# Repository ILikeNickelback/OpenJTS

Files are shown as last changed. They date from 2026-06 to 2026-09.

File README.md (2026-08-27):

# OpenJTS

Open-source JTS (Joliot-type Spectrophotometer).
Designed for measuring light-induced signals in photosynthesis research using fluorescence and spectroscopy protocols.
Two acquisition modes are supported: sequence mode and frequency mode.
---

## Overview

This OpenJTS project includes the necessary software to control the JTS, the PCB design and BOMs, the stp files and the docs.
Certain manuals might be found on other adresses for easier reading.

## Requirements

### Hardware
- MCC DAQ board (compatible with [mcculw](https://github.com/mccdaq/mcculw))
- ESP32 microcontroller connected via USB serial

### Software
- Windows 10/11 (64-bit)
- [pixi](https://prefix.dev/) — used for environment and dependency management

---

## Installation

**1. Install pixi** (if not already installed):

```powershell
iwr -useb https://pixi.sh/install.ps1 | iex
```

**2. Clone the repository:**

```powershell
git clone https://github.com/ILikeNickelback/OpenJTS.git
cd OpenJTS
```

**3. Install the environment:**

```powershell
pixi install
```

This resolves all dependencies from `pixi.toml` using the conda-forge channel, including Python 3.14, NumPy, DearPyGUI, mcculw, loguru, and pyserial.

---

## Running

```powershell
pixi run python software/src/main.py
```

The application opens maximised at 1920×1200. Per-monitor DPI scaling is applied automatically.

---

## Project structure

```
OpenJTS/
├── software/
│   └── src/
│       ├── main.py                   # Entry point
│       ├── config/
│       │   ├── config.json           # ADC, ESP32, LED, and app settings
│       │   ├── sequences.json        # Saved sequence / frequency library
│       │   └── fonts.py              # DPG font setup
│       ├── core/
│       │   ├── app_state.py          # Shared application state
│       │   ├── event_bus.py          # Pub/sub event bus
│       │   ├── layout.py             # Window creation and tab registry
│       │   ├── layout_manager.py     # Panel position/size configuration
│       │   ├── window_base.py        # Base class for all panel windows
│       │   └── workspace_manager.py  # Save / load workspace JSON
│       ├── hardware/
│       │   ├── adc_base.py           # MCC DAQ base driver (buffer, reader thread)
│       │   ├── adc_sequence.py       # Sequence-mode ADC subclass
│       │   ├── adc_frequency.py      # Frequency-mode ADC subclass
│       │   ├── adc_calibration.py    # Calibration ADC subclass
│       │   └── esp32.py              # ESP32 serial driver
│       ├── workers/
│       │   ├── base_worker.py        # Threaded acquisition base class
│       │   ├── sequence_worker.py    # Worker for sequence acquisitions
│       │   ├── frequency_worker.py   # Worker for frequency acquisitions
│       │   └── calibration_worker.py # Worker for 1 Hz LED calibration
│       ├── sequence_builders/        # Sequence language parser and preview builder
│       ├── windows/
│       │   ├── main_window.py        # Top-level DPG window and menu bar
│       │   ├── home_window.py        # Home tab (device status, experiment list)
│       │   ├── experiment/           # Per-experiment tab and sub-tab builders
│       │   ├── panels/               # Control panels (settings, library, metadata…)
│       │   └── plots/                # Lineplot and sequence preview plot
│       └── utils/
├── pixi.toml                         # Dependency manifest
└── pyproject.toml                    # Ruff lint config
```

---

## Configuration

All settings live in `software/src/config/config.json`:

```json
{
  "General":  { "app_name": "JTS", "fontsize": 15 },
  "ADC":      { "board_num": 0, "channel_count": 8, "sampling_rate": 200000 },
  "LED":      { "actinic_light_max": 100, "detection_light_max": 100 },
  "ESP32":    { "baud_rate": 115200, "timeout": 1 },
  "Sampling": { "samples_per_trigger": 8, ... }
}
```

The sequence and frequency preset library is stored in `software/src/config/sequences.json` and is editable directly from the **Sequence library** panel inside the application.

---

## Sequence language

Sequences are written in a compact domain-specific language. A few examples:

| Token | Meaning |
|---|---|
| `D` | Detection pulse |
| `A[100]` | Set actinic light to 100 % |
| `300µs` | 300µs delay|
| `4(100msD)` | Repeat `100msD` four times |
| `L` | Laser |
| `T` | Set time start point |

Example — ECS measurement:
```
4(100msD) A[100] 50ms A[0] 300µsD 1msD 2msD 5(5msD) 5(10msD) 5(20msD) 5(50msD) 5(100msD)
```

---

## Key features

- **Multiple experiments** — open several experiment tabs simultaneously, each with its own isolated event bus, settings, and results.
- **Averaging and ignore runs** — configurable per sequence: discard N warm-up runs then average M acquisitions.
- **Baseline subtraction** — subtract the mean of the first N points from every result.
- **Live plot** — real-time streaming of incoming ADC data during acquisition.
- **Sample container** — name, toggle, and export individual result series to JSON.
- **Sequence history** — timestamped log of every completed acquisition.
- **Workspace save / restore** — full experiment state (sequences, parameters, results, metadata) saved to JSON and reloadable.
- **Autosave** — a snapshot is written to `software/src/temp/autosave.json` after every completed acquisition.

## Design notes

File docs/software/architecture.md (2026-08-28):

# Architecture

## What It Is

OpenJTS is a desktop application (Python 3.14) for running experiments on the OpenJTS hardware. The user defines a sequence of light pulses and sees the results plotted in real time. It drives a specific DAQ board and can interact with an ESP32 over serial. The UI is built on the **DearPyGui (DPG)** library.

---

## Architecture

Launching `main.py` creates a DPG context and viewport, initializes the ADC and ESP32 instances, and starts the render loop, which updates the UI each frame in response to events.

The app is event-driven, built on two pillars:

- **AppState** — a single shared object holding all runtime data (experiments, sequences, parameters, hardware references). It is passed into every window at construction.
- **EventBus** — a publish/subscribe message broker. Windows never call each other directly; they publish named events with keyword arguments, and subscribers are invoked synchronously.

---

## Threading

OpenJTS makes heavy use of threads and queues, driven by one DPG constraint: item creation, deletion, and configuration must happen on the main DPG thread. Threads communicate by writing to queues that other threads can safely read.

There are four thread roles:

- **Main thread** — owns all DPG item creation, deletion, and configuration, the per-frame callback, and event dispatch.
- **Worker thread** — waits on a command queue and manages the acquisition: starts/stops it, launches the ADC reader thread, and turns raw data blocks into scalar points pushed to the result queue.
- **ADC reader thread** — polls the ADC every 1 ms, accumulating samples into a trigger block; when the block is full (one detection pulse) it pushes to the data queue.
- **Polling thread** — reads the result queue and applies statistical processing (averaging, baseline, etc.), then hands results to the main thread for plotting.

In short: the reader collects raw samples, the worker turns them into scalar data points, the polling thread does statistical processing and routing, and the main thread owns all rendering.

---

## Window Hierarchy

- **Main window** — top-level DPG primary window; hosts the menu bar (File, Tools) and the `TabbedWindowManager`.
- **Home window** — static tab showing device connection status and a table of all experiments with their metadata.
- **Experiment tab** — one experiment's content, with its own isolated `tab_bus` and a nested sub-tab bar.

---

## Acquisition Pipeline

The flow from user input to plotted results:

**Define → Load → Start → Acquire → Return → Display**

1. **Define** — the user types sequence strings (e.g. `4(100msD)A[100]20msA[0]300µsD`); multiple sequences are allowed.
2. **Load** — the decoder expands repeats and converts units into a token list stored in `AppState`, then publishes `sequence_list_ready`.
3. **Start** — resets the sequence index, records the start time, and dispatches `configure` + `start` commands to the worker.
4. **Acquire** — the worker reads blocks from the ADC, computes ΔI/I per block, and streams live points back through the result queue.
5. **Return** — the polling thread applies baseline subtraction and averaging, then routes finished results to the main thread through a thread-safe queue.
6. **Display** — the main thread drains that queue each frame and publishes to the UI, updating the plot and sample container.

> For the internals of any stage — decoding rules, the total-time formula, baseline/averaging logic, event names and payloads — see the inline comments and autodocs.

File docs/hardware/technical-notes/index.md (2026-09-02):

# Technical notes

This section details the technical choices for the different modules when it is needed.

```{toctree}
:maxdepth: 2
:caption: Technical notes

LED-control
optical-transmission
measurement-strategy
preamp-design
VCCS-design
waveform-generation
```

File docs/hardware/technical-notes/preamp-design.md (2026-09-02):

# Transimpedance Amplifier Design

The transimpedance amplifier (TIA) is a critical building block of the JTS optical detection system. It is responsible for converting the photocurrent emitted by the photodiode into a stable, low-noise voltage readable by the Data Acquisition (DAQ) system.

A useful baseline reference on stable TIA design principles is available via [DigiKey's TIA Design Guide](https://www.digikey.fr/fr/articles/how-to-design-stable-transimpedance-amplifiers-automotive-medical-systems).

---

## 1. System Specifications & Constraints

Designing the TIA requires balancing **gain, bandwidth, and linearity**. A primary challenge is managing the wide dynamic range of optical signals: varying optical filters or samples significantly changes light transmission. The TIA gain must resolve small signals without saturating under peak light levels (though light intensity from the excitation LED can be modulated).

### Photodiode Characteristics
Based on the photodiode specifications, the sensor is a Hamamatsu Si PIN photodiode reverse-biased at **48 V**, yielding:
- **Terminal Capacitance ($C_d$):** $\approx 47\text{ pF}$
- **Dark Current:** Negligible (a few nA)

### Bandwidth Target
To resolve a **20 µs** light pulse without excessive edge rounding, the amplifier's rise time ($t_r$) should be roughly $\frac{1}{17}$ of the pulse width:

$$t_r \approx \frac{20\text{ }\mu\text{s}}{17} \approx 1.2\text{ }\mu\text{s}$$

$$f_{-3\text{dB}} = \frac{0.35}{t_r} \approx 300\text{ kHz}$$

We establish **300 kHz** as the minimum closed-loop bandwidth target for every gain range.

### Feedback Resistance Choice
The highest expected photocurrent is around **50 µA**. The ADC can accept up to **+10 V**, so the maximum allowable feedback resistance is:

$$R_f = \frac{U}{I} = \frac{10\text{ V}}{50\text{ }\mu\text{A}} = 200\text{ k}\Omega$$

To maintain high dynamic range without complex dynamic range switching, the feedback resistance is fixed at **$R_f = 200\text{ k}\Omega$**.

### Stability Equations
The photodiode's terminal capacitance ($C_d$) creates a pole with the feedback resistor ($R_f$) that erodes phase margin and causes gain peaking/ringing if left uncompensated. A feedback capacitor ($C_f$) in parallel with $R_f$ restores phase margin.

The standard TIA design equations are:

$$f_{-3\text{dB}} \approx \sqrt{\frac{\text{GBW}}{2\pi \cdot R_f \cdot C_d}}$$

$$C_f \approx \frac{1}{2\pi \cdot R_f \cdot f_{-3\text{dB}}} \approx \sqrt{\frac{C_d}{2\pi \cdot R_f \cdot \text{GBW}}}$$

---

## 2. Architectural Options

### Option A: Single-Stage High-Voltage TIA

A single transimpedance stage converts photocurrent directly into a $\pm 10\text{ V}$ signal driving the ADC.

```
                  +---| Rf (200 kΩ) |---+
                  |                     |
                  +---| Cf (~1.3 pF)|---+
                  |                     |
[ Photodiode ] -> (- Inverting )        |
                  (            ) [ Op-Amp ] ----> [ Low-Pass Filter ] -> [ ADC (±10V) ]
     ( Ground ) -> (+ Non-Invert)
```

#### Key Requirements:
- **Gain-Bandwidth Product (GBW):** Minimum **$5.3\text{ MHz}$** to hit 300 kHz bandwidth with $R_f = 200\text{ k}\Omega$ and $C_d = 47\text{ pF}$.
- **Input Bias Current ($I_b$):** Must be ultra-low (FET/CMOS input, $\le 10\text{ pA}$) to prevent significant DC offset errors across $200\text{ k}\Omega$.
- **Power Supply Rails:** Must support $\pm 15\text{ V}$ or $\pm 12\text{ V}$ to deliver full $\pm 10\text{ V}$ output to the ADC.

#### Suitable Op-Amp Candidates:
- **ADA4622-1:** JFET input, $\text{GBW} = 8\text{ MHz}$, $I_b = 10\text{ pA}$, $\pm 15\text{ V}$ supplies.
- **ADA4637-1:** High-speed JFET, $\text{GBW} = 79\text{ MHz}$, $I_b = 1\text{ pA}$, $\pm 15\text{ V}$ supplies.

---

### Option B: Two-Stage Architecture (OPA657 + AD797)

A hybrid approach decoupling the ultra-low noise, high-speed current conversion stage from the high-voltage voltage gain stage.

```
=== STAGE 1: TIA Stage (±5V Supply) ===       === STAGE 2: Voltage Gain Stage (±15V Supply) ===

                  +--| Rf1 (50 kΩ) |--+                                 +--| Rf2 (3 kΩ) |--+
                  |                   |                                 |                  |
                  +--| Cf1 (4.3 pF) |-+                                 +--| Rg2 (1 kΩ) |--+
                  |                   |                                                    |
[ Photodiode ] -> (- Inv )            |                                  (- Inv )          |
                  ( OPA657 ) ---------+-----> [ AC/DC Coupling ] ------> ( AD797 ) --------+--> [ ADC (±10V) ]
     ( Ground ) -> (+ Non-Inv )                                          (+ Non-Inv )
                                                                              |
                                                                          ( Ground )
```

#### Stage 1: Current-to-Voltage (OPA657)
- **Role:** High-speed TIA operating on low-voltage rails ($\pm 5\text{ V}$).
- **Performance:** JFET inputs ($I_b \approx 2\text{ pA}$), ultra-high bandwidth ($\text{GBW} = 1.6\text{ GHz}$), ultra-low voltage noise ($4.8\text{ nV}/\sqrt{\text{Hz}}$).
- **Stability Note:** The OPA657 is a *decompensated* op-amp stable only for high-frequency noise gain $\ge 7$. With $C_d = 47\text{ pF}$ and $C_f \approx 4.3\text{ pF}$, the high-frequency noise gain is:
  $$\text{Noise Gain}_{\infty} = 1 + \frac{C_d}{C_f} = 1 + \frac{47\text{ pF}}{4.3\text{ pF}} \approx 11.9$$
  Since $11.9 > 7$, Stage 1 is inherently stable.

#### Stage 2: Voltage Gain & Level Shifting (AD797)
- **Role:** Voltage amplifier running on $\pm 15\text{ V}$ rails to scale the Stage 1 output to match the ADC's $\pm 10\text{ V}$ range.
- **Performance:** Driven by the low-impedance output of Stage 1, erasing input bias current limitations ($250\text{ nA}$) while delivering ultra-low noise ($0.9\text{ nV}/\sqrt{\text{Hz}}$).

#### Power Supply Infrastructure:
- Requires dedicated **linear voltage regulators (LDOs)** (e.g., ADP7118 / ADP7182 or 78L05 / 79L05) to generate clean $\pm 5\text{ V}$ rails from the main $\pm 15\text{ V}$ supplies. *Resistor voltage dividers cannot be used for powering the OPA657 due to dynamic current draw variations.*

---

## 3. Comparison Matrix

| Feature / Metric | Option A: Single-Stage (e.g. ADA4622) | Option B: Two-Stage (OPA657 + AD797) |
|---|---|---|
| **Circuit Complexity** | Low (Single IC, simple layout) | Medium-High (2 ICs, LDO regulators) |
| **Supply Rails** | Single dual-rail pair ($\pm 15\text{ V}$) | Dual rail pairs ($\pm 5\text{ V}$ LDOs & $\pm 15\text{ V}$) |
| **Noise Performance** | Good (limited by single-stage trade-offs) | Superior (ultra-low noise OPA657 front-end) |
| **Bandwidth Headroom** | Moderate (8–79 MHz GBW) | Exceptional (1.6 GHz GBW front-end) |
| **PCB Footprint** | Small | Moderate |

---

## 4. Downstream Filtering & Protection

- **Anti-Aliasing Filter:** A single-pole RC low-pass filter ($f_c \approx 500\text{ kHz} - 1\text{ MHz}$) follows the TIA before the ADC to restrict out-of-band noise without distorting 300 kHz signals.
- **ADC Protection:** The DAQ system's ADC input natively tolerates overvoltage up to **$\pm 25\text{ V}$**. Because the maximum output from an AD797 or single $\pm 15\text{ V}$ stage is $\approx \pm 13.5\text{ V}$, **no protective clamping diodes are required**, preventing parasitic diode capacitance from degrading high-frequency signal integrity.

---

## 5. Critical PCB Layout Guidelines

1. **Summing Node Isolation:** Keep $R_f$, $C_f$, and photodiode trace lengths as short as physically possible, routing directly to the op-amp inverting pin.
2. **Ground Plane Clearance:** Cut away (void) the internal ground and power plane copper directly underneath the inverting input pin, photodiode anode pad, and feedback traces to eliminate parasitic capacitance loading the input.
3. **Guard Ringing:** Surround the inverting node with a grounded guard trace driven near the same potential to prevent surface leakage currents across high-resistance feedback paths.
4. **Supply Separation:** Keep the **48 V** photodiode reverse-bias line isolated and well-filtered from sensitive analog signal traces to prevent power supply ripple from coupling into the summing node.

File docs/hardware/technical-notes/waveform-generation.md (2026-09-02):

# Waveform Generation

OpenJTS produces its actinic and detection light through **two independent paths**:

- The **DAQ board** (an MCC card, driven by [`hardware/adc_base.py`](../../../software/src/hardware/adc_base.py) and its subclasses) generates the full, timing-critical stimulus waveform for real acquisitions — actinic light, detection flashes, and the trigger that tells the acquisition side when to sample — all locked to a single 500 kHz clock.
- The **ESP32** (documented in [Firmware](../../firmware/firmware.md)) is a simpler, general-purpose controller. In the current software it is mostly used for one-shot commands (set a constant actinic level, stop), but its firmware also implements a full standalone sequencer with its own DAC and digital trigger outputs, including a laser trigger the DAQ path does not have.

This note explains how each side actually turns numbers into light, given the channel and resolution constraints each hardware has to work with.

---

## 1. DAQ Board: One 16-bit Waveform, Three Channels, 500 kHz

### 1.1 The channel budget

The board's output scan is started with a single call:

```python
ul.daq_out_scan(
    self.board_num,
    [0, 1, 1],
    [ChannelType.ANALOG, ChannelType.ANALOG, ChannelType.DIGITAL],
    [ao_range, ao_range, ULRange.NOTUSED],
    3,
    self.rate,                       # 500 000 Hz
    self._total_waveform_samples * 3,
    self._memhandle,
    options=(ScanOptions.BACKGROUND | ScanOptions.CONTINUOUS),
)
```

— [`ADCBase.start_acquisition()`](../../../software/src/hardware/adc_base.py)

Three channels, no more: **AO0** (actinic), **AO1** (detection), and one **digital port** (trigger). There is nothing left over for a laser-trigger channel, which is why the DAQ path currently cannot drive a laser — `sequence_waveform_builder.py` parses the `L` (laser) token from a sequence string but its handler is a no-op:

```python
elif item["type"] == "laser":
    pass
```

— [`SequenceWaveformBuilder._parse_sequence` / `build()`](../../../software/src/sequence_builders/sequence_waveform_builder.py)

The ESP32 firmware *does* have two dedicated laser-trigger pins (§2.3) — that logic has simply not been ported to the DAQ-driven waveform yet, because doing so would need a fourth output channel this board doesn't have to spare.

### 1.2 One buffer, interleaved

The board has no concept of "three separate waveforms." It streams a single flat `uint16` array, and consumes it three samples at a time — one value per channel, in channel order, per output tick:

```
index:   0    1    2    3    4    5    6    7    8   ...
         ch0  ch1  ch2  ch0  ch1  ch2  ch0  ch1  ch2  ...
         └── tick 0 ──┘└── tick 1 ──┘└── tick 2 ──┘
```

Both waveform builders ([`SequenceWaveformBuilder`](../../../software/src/sequence_builders/sequence_waveform_builder.py) for the sequence mini-language, [`FrequencyWaveformBuilder`](../../../software/src/sequence_builders/frequency_waveform_builder.py) for sine-modulated acquisitions) build this interleaved array in Python with NumPy strided views (`interleaved[0::3]`, `[1::3]`, `[2::3]`) so each channel can be filled independently before being copied into the DMA buffer:

```python
interleaved = np.empty(total_samples * 3, dtype=np.uint16)
ch0_raw = interleaved[0::3]   # actinic
ch1_raw = interleaved[1::3]   # detection flash
ch2_raw = interleaved[2::3]   # trigger marker
```

Because all three channels are drawn from the *same* buffer at the *same* clock, they are sample-accurate relative to each other — the trigger marker, the detection flash, and the actinic level at any instant are guaranteed to be aligned to within one 2 µs tick (1 / 500 kHz). That's what makes it possible to hit the 2–3 µs sampling window described in [Measurement Strategy](measurement-strategy.md) without any drift between the light and the acquisition trigger.

### 1.3 16-bit resolution, ±10 V range

The board's AO range is bipolar ±10 V, addressed with the full 16-bit count space (`counts_max = 65535`). A percentage intensity (0–100 %) is mapped to a count with:

```python
counts = counts_max * (0.5 + 0.5 * intensity_percent / 100) - offset
```

so 0 % sits near mid-scale count (0 V) and 100 % sits near full-scale count (+10 V) — the same 0.5 + 0.5·x mapping is used for both the actinic channel (ch0) and the detection flash amplitude (ch1). The `offset` term (`actinic_light_offset` / `detection_light_offset` in `config.json`) compensates for the LED driver / VCCS non-linearity described in [VCCS Design](VCCS-design.md).

### 1.4 Channel 0 — actinic light

Ch0 carries whatever actinic waveform the experiment calls for:

- **Sequence mode** — a step function: each `N!` token in the sequence string sets a constant count from that point forward, until the next `N!` token overwrites it (`ch0_raw[current_sample:] = intensity_counts`).
- **Frequency mode** — a genuine sine wave, sampled at the full 500 kHz rate: `sine = amplitude * np.sin(2*np.pi*freq*t + phase) + offset`, converted to counts sample-by-sample. Because the analog output is a real DAC stream and not a switched PWM signal, arbitrary waveforms (sine, or anything else) come for free — this is the same reasoning behind choosing analog output + VCCS over PWM in [LED Control](LED-control.md).

### 1.5 Channel 1 — detection flash

Ch1 stays at 0 except for 20 µs analog pulses (`pulse_width_samples = int(rate * 20e-6)` → 10 samples at 500 kHz), placed either at each `D` token (sequence mode) or on an evenly-spaced grid of `normal_pulses_per_period` flashes per sine period (frequency mode). Because this is a genuine analog channel, the flash amplitude is fully adjustable (`detection_led_intensity`, 0–100 %) — unlike the ESP32's detection output (§2.2), which is only ever fully on or fully off.

### 1.6 Channel 2 — the trigger

Ch2 is digital: each sample is either `0` or `0xFFFF` (all bits of the port driven at once). It is used purely to mark acquisition timing for the AI (input) scan, which is started with `ScanOptions.EXTTRIGGER | RETRIGMODE` — every rising edge on this channel re-arms the input scan and captures `samples_per_trigger` points. Two kinds of markers are written per flash:

- `number_of_points_before_flash` short (10 µs) pre-pulses, 50 µs apart, ending flush with the start of the analog flash — these sample the baseline used for the DC-subtraction described in [Measurement Strategy §2](measurement-strategy.md#2-dc-component-subtraction).
- One pulse during the flash itself, offset 3 samples (6 µs) into it, timed to land just before the flash ends.

So the "3 channels" the DAQ board offers map exactly onto the three physical needs: one analog output for actinic light, one analog output for the detection flash, and one digital line to tell the input side exactly when to look — with no channel left to spare for anything else, laser included.

---

## 2. ESP32: Many Digital Pins, Two 8-bit DACs

The ESP32 firmware ([Firmware](../../firmware/firmware.md)) drives light with completely different building blocks: it has no synchronized multi-channel waveform engine, but it has dozens of general-purpose GPIOs and exactly two on-chip 8-bit DAC channels to work with.

### 2.1 The two onboard DACs

The ESP32 SoC exposes only two analog outputs in hardware, `DAC_CHANNEL_1` (GPIO25) and `DAC_CHANNEL_2` (GPIO26), each 8-bit (0–255 counts). OpenJTS uses only one of them:

| Pin | GPIO | Role |
|---|---|---|
| `actinicDacPin` | 26 | Actinic level — true analog output via `DAC_CHANNEL_2`, `dacWrite()` |
| `detectorDacPin` | 25 | Detector LED — sits on `DAC_CHANNEL_1` but is driven as a **plain digital** GPIO, fully on/off |

So of the two available 8-bit DACs, only the actinic channel is actually used as an analog output. `writeActinicLevel()` also works around a hardware quirk: DAC code 0 still outputs a small non-zero floor voltage (tens to hundreds of mV), enough to keep a sensitive LED driver visibly lit — so a request for level 0 disables the DAC channel entirely and drives the pin `LOW` instead, rather than writing count 0.

Resolution-wise this is much coarser than the DAQ board's 16-bit output (256 levels vs. 65 536), which is acceptable here because the ESP32 path is only ever asked for a static or steppped actinic level (`O<percent>` command, or `N!` inside a sequence) — it has no equivalent to the DAQ's sine-wave modulation, since `dacWrite()` is a single static register write, not a clocked waveform generator.

### 2.2 Detection light is digital-only

The detection LED pin (GPIO25) is capable of being a DAC, but the firmware never uses it that way — it is toggled with direct `GPIO_SET`/`GPIO_CLR` register writes for speed, fully on for a fixed 18 µs window and fully off otherwise (`detection_trigger()`). There is no equivalent of the DAQ board's adjustable detection-flash amplitude (§1.5): on the ESP32 path, the detection flash is binary, and its "channel" is really just one digital output line rather than an analog one.

### 2.3 A lot of digital pulse outputs

Beyond the one analog channel, the firmware drives everything else — trigger and laser synchronization — as plain digital pulses, using direct register writes rather than `digitalWrite()` so edges stay sharp at microsecond timescales:

| Pin | GPIO | Role |
|---|---|---|
| `TriggPin` | 12 | Brackets a detection event with two short pulses, for an external DAQ |
| `laserChannel_open` | 18 | Laser channel "open" trigger pulse |
| `laserChannel_start` | 19 | Laser channel "start" trigger pulse |

`setup()` maxes out pad drive strength (`GPIO_DRIVE_CAP_3`) on all four pulse-critical pins so their edges stay sharp even while the actinic LED's current draw sags the supply rail. Because the ESP32 exposes dozens of GPIOs in total, this scheme could in principle be extended with more digital trigger lines (further laser channels, additional external sync outputs, etc.) at essentially no hardware cost — the constraint on this path is not "how many pins are available" the way it is on the DAQ board, but simply which ones the firmware currently wires up.

`laser_trigger()` is the one capability that exists here and not on the DAQ side: it pulses `laserChannel_open` high for 10 µs, waits 160 µs, then pulses `laserChannel_start` high for 10 µs — a fixed two-edge handshake a laser's own controller can use to fire in sync with the sequence, something the 3-channel DAQ waveform (§1.6) has no spare channel to reproduce.

### 2.4 Summary: two different trade-offs

| | DAQ board | ESP32 |
|---|---|---|
| Output channels | 3 total (2 analog + 1 digital), fixed by the scan call | Dozens of GPIO, 2 onboard 8-bit DACs (only 1 used) |
| Resolution | 16-bit (65 536 counts) on both analog channels | 8-bit (256 counts) on the one DAC used |
| Sample rate | 500 kHz, single shared clock across all 3 channels | No fixed clock — pulses are timed procedurally in firmware |
| Detection flash | Analog, adjustable amplitude | Digital, on/off only |
| Actinic waveform | Arbitrary (step or sine), sample-accurate | Step changes only |
| Laser control | Not wired (no spare channel) | Two dedicated trigger pins |

The two paths are complementary rather than redundant: the DAQ board buys synchronized, high-resolution, arbitrary-waveform light generation at the cost of a hard 3-channel ceiling; the ESP32 buys effectively unlimited digital I/O (including laser triggering) at the cost of coarser, non-synchronized analog control.

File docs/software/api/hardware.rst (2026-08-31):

hardware
========

.. automodule:: hardware

.. rubric:: Modules

.. autosummary::
   :toctree:
   :recursive:

   adc_base
   adc_calibration
   adc_calibration_external
   adc_frequency
   adc_sequence
   adc_sequence_external
   esp32

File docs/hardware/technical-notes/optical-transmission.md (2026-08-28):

# Optical Transmission

## Background

The first JTS designs used xenon flash lamps to produce the detection flashes. Xenon lamps give short and powerful flashes, but they are very unstable from one flash to the next. This is a real problem in differential spectroscopy: the absorption changes being measured are small, so fluctuations in the intensity of the detection light are enough to hide them.

The solution was to send the same flash to two channels and normalise one against the other. One channel holds the sample (the **measurement channel**); the other holds only a shutter (the **reference channel**), used to balance the light intensity between the two. At each time point, the reference is subtracted from the measurement and the result is divided by the reference:

```
signal = (I_measurement − I_reference) / I_reference
```

Any variation common to both channels therefore cancels out.

---

## Detection Flashes

### Constraint

The detection flashes must be stable, powerful, and synchronised between the two channels.

### Options

Two optical designs have historically been used to bring the same detection light to both channels:

- A semi-reflecting mirror (beam splitter)
- A Y-shaped optical fibre

Each has advantages and drawbacks.

A third option is to use two separate LEDs controlled by the same circuit. In this case, normalisation only rejects supply- and driver-level noise, not LED-level noise — though this is likely acceptable given how stable modern LEDs are.

### Choice

Two modern LEDs, one per channel, driven by the same circuit.

### Reasons

Modern LEDs are far more stable than xenon lamps and are powerful enough for the measurement, so the flash no longer needs to be split from a single source. In addition, the actinic light is not transmitted through fibre optics, avoiding the need for an expensive fibre optic component.

---

## Light Filters

### Constraints

The detection flashes and actinic flashes must be filtered correctly according to the experiment the user wants to run.

### Options

For the detection light, previous JTS models used one of the following:

- A monochromator
- A VariSpec (liquid crystal tunable filter)
- A choosable detection light array offering many colors
- Flat round filters
- Double linear filter

### Choice

For the OpenJTS, we will use **flat round filters**.

### Reasons

This is the cheapest and simplest way to filter the detection light.

---

## Photodiode

### Constraint

We need to precisely measure light intensity from 20 µs pulses with the best possible signal-to-noise ratio (SNR).

### Options

When choosing a photodiode, several attributes come into play:

- **Photosensitive area** — determines how many photons will be captured; a larger surface yields more signal.
- **Spectral response range** — must cover the entirety of the desired spectral range.
- **Terminal capacitance** — determines response speed; lower capacitance increases bandwidth.
- **Reverse voltage** — reverse voltage lowers terminal capacitance and increases bandwidth, but also increases dark noise.
- **Dark current** — current noise present when the photodiode is in the dark.

Many different models are possible.

### Choice

We used the Hamamatsu Si PIN photodiode **[S ….. BQ]**, reverse-biased at 48 V.

### Reasons

This model has one of the largest photosensitive areas, a good spectral response range, and a low terminal capacitance. In addition, a 48 V reverse bias drops the terminal capacitance to 47 pF, which suits our 20 µs pulses well. The resulting dark current of a few nA is negligible.

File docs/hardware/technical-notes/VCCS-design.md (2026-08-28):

# VCCS Design

For this version of the JTS, we are using the analog output of an ADC and a VCCS to control the actinic LED.

---

## What Is a VCCS?

VCCS stands for **Voltage Controlled Current Source**. As the name suggests, it is an electronic circuit that lets you control a current proportionally to a voltage, regardless of what load is connected to the output.

---

## Why a VCCS?

We are using LEDs to produce actinic and detection light. However, LED intensity is not linear with voltage, but with current.

It is possible to use a matrix of resistors and transistors to select light intensity, where each resistor determines the current going through the LED.

Alternatively, we can use the analog output of an ADC — which outputs a voltage from 0 to 10 V with 32,000 possibilities in between — combined with a VCCS. This lets the user select a large range of light intensities with a simple circuit and software controlling the ADC. This design also permits actinic light patterns such as sine waves or anything else.

Alternatively, we could also use a PWM with a VCCS, but this will be explored in a future version.

---

## How to Build a VCCS?

A simple VCCS is composed of the following components:

- A differential or op amp
- A MOSFET or BJT
- A LED (or any current-driven load)
- A sense resistor (or shunt resistor)

R1 and R2 are optional.

### How Does It Work?

As with any amplifier, the circuit continuously compares the input voltage to the feedback loop.

- The input voltage is regulated by the ADC in our case.
- The feedback voltage is proportional to the current going through it (V = I × R).
- Any difference between the two is corrected by the op amp.
- The difference signal drives a transistor that acts as the variable current valve.
- The op amp drives the transistor gate/base until the voltage across R_sense equals V_in, so:

```
I_out = V_in / R_sense
```

### Important Notes

- The LED supply should be powerful enough to drive the LED and sense resistor.
- For a given I_out, a smaller R_sense gives a smaller V_sense, and so a bigger SNR. For example, if you want 100 mA and R_sense = 1 Ω, V_sense = 100 mV. But if R_sense = 0.01 Ω, V_sense = only 1 mV.
- For a given V_in, a bigger R_sense gives better control but more power loss.

---

## Final Design for the JTS

There are some differences from the basic design.

### Voltage Divider

**Constraints**

We are using a 48 V generator with a 38 V LED. The MOSFET uses up around 1–2 V. This leaves around 8 V of headroom for the sense resistor. If we send a 10 V signal to V_in, the signal will saturate at 8 V. Practically, during construction, we observed a saturation level for a signal around 3–4 V.

**Options**

We can either use a larger power supply or add a voltage divider on the analog output to lower V_in.

**Choice**

We are using a voltage divider that lowers V_in by a factor of around 5, so 10 V becomes 2 V.

**Reasons**

Both solutions are possible, but we chose to use a voltage divider because it is simple to make and can be adapted to any power supply.

### MOSFET

The transistor being used is an N-type power MOSFET. It needs to be able to withstand at least 2 A of current and needs a fast switching time. The **IRF540N** fits perfectly for this circuit.

### Op Amp

We are using the **AD797** for this circuit because of its low voltage noise. We had many in stock at the time of making the circuit. It can be substituted for another op amp.

### Sense Resistor

The sense resistor should be small enough to deliver enough power to the actinic light, and big enough that the output signal has a good SNR. The maximum output should be near saturating, but there should also be enough low light levels to perform certain experiments.

We chose **30 Ω** for this resistor, as it fits well with our constraints.

### C1 Capacitor

This capacitor was added to filter out high-frequency noise observed on the photodiode. This high-frequency noise is probably due to the high impedance of the MOSFET gate, which acts like a capacitance. As a result, the MOSFET can open and close in an unpredictable manner. This problem was easily solved by adding a small capacitor between gate and source, filtering out the high-frequency noise.

### R3 and R4 Resistors

These resistors are not mandatory, but they help with stability and avoid ringing.

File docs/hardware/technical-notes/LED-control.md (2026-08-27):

# Technical choices: LED control

The JTS uses two types of LED:

- LEDs for the detection light
- LEDs for the actinic light

## 1. Detection LED

**Requirements:**

- The colour is chosen according to what the user wants to observe.
- The LED must deliver a clean, stable, short and powerful light pulse of a defined intensity.

### 1.1 Colour

**Constraint.** The emission colour must match the requirements of the experiment, both in wavelength and in intensity (for example, blue for fluorescence measurements).

**Options.**

The first option is to use an LED of exactly the colour required, for example a blue LED for fluorescence. This works well if several LEDs of different colours are mounted together and selected by software, but it means either a controller with many PWM outputs, each with its own transistor and resistor, or an equivalent array of transistors and resistors. A single LED can also turn out to be too weak for the measurement.

The second option is to use an LED array with a flat spectral output across the visible range (400–800 nm) and to select the colour with filters, for example a blue filter for fluorescence. Only one controller output is then needed to drive the LED, which greatly simplifies the electronics. The trade-off is that a good filter set is required, and some residual light outside the wanted band is always transmitted.

The two approaches can also be combined: single-colour LEDs together with filters.

**Choice.** For the OpenJTS model we use a single array of white LEDs (Sunlike COB) together with coloured filters.

**Reason.** Sunlike COB LEDs are cheap, easy to drive and have a flat spectral output. Coloured filters are easy to obtain and easy to use.

### 1.2 Intensity

**Constraint.** The LED must be able to deliver pulses as short as 20 µs, with enough power and good stability.

**Options.**

A short, powerful pulse of a defined intensity requires a powerful LED and one of the following drive schemes: a controller with an array of transistors and resistors, PWM through a single transistor and resistor, or an analogue output driving a single transistor and resistor or a VCCS. Whichever is chosen, the driver must be able to produce a clean 20 µs pulse.

A few practical points:

- A 100 Ω resistor on the output limits ringing.
- A MOSFET is recommended as the switching element.
- A fairly low resistor (10–100 Ω) between the drain and the power supply gives the best compromise between power and stability.
- The power supply must be able to drive the LED and deliver enough power; it can be linear or switching.
- Supply filtering with a one- or two-stage filter is essential for stable pulses.
- A gate driver can also be used to obtain a clean, stable pulse at the gate.

**Choice.** For the detection LED we use a switching 48 V power supply with a two-stage filter, an IRF540N MOSFET and a 50 Ω shunt resistor. A gate driver has not been tested yet.

**Reasons.** The LED we selected needs at least 38 V, so the supply was chosen with enough headroom and with the ability to deliver high power during short pulses. Since a switching supply is relatively noisy, a two-stage filter is used to cut high-frequency noise; this is critical given the very short pulses and the high instantaneous load. The IRF540N handles the required power, is quiet and switches fast. The 50 Ω shunt resistor was chosen empirically, as it gives enough power while keeping the pulse stable. A gate driver has not yet been evaluated.

**Further notes.** Because of the large load and the fast switching, the circuit shows significant stray inductance, which perturbs the output voltage of the transimpedance amplifier (V = −L × dI/dt). The actinic and detection ground return paths must therefore be properly separated.

## 2. Actinic LED

**Requirements:**

- The colour is chosen according to what the user wants to observe.
- The length and intensity of the pulse must be easy to change.
- It must be possible to send amplitude-modulated light.

### 2.1 Colour

**Constraint.** The colour is chosen according to what the user wants to observe.

**Options.** An array of LEDs of different colours (for example red, far red or blue) can be used, with the active colour selected either manually or digitally. Depending on their characteristics, the different colours may need different power supplies.

**Choice.** We currently use an array of blue, red and far-red LEDs. All colours sit on a single chip, but each has its own power cable; the user selects a colour by plugging in the corresponding cable.

**Reason.** The user can change the actinic colour quickly.

**Note.** The new model currently provides red light only, as this is the most frequently used colour.

### 2.2 Length and intensity

**Constraint.** The user must be able to set the length and the intensity of the actinic light within a sequence. These values are programmed in advance, in the sequence itself: the intensity cannot be changed in real time while the sequence is running. Actinic pulses are comparatively long, from a few milliseconds to several seconds, so stability matters much less than it does for the detection LED. The LED array we designed runs from a 15 V supply, linear or decoupled; filtering is not needed but encouraged given the pulse lengths.

**Options.** A controller with an array of transistors and resistors, PWM through a single transistor and resistor, or an analogue output driving a VCCS.

**Choice.** We currently use an analogue output driving a VCCS, with a 15 V linear power supply.

**Reasons.** This combination gives access to a wide range of light intensities and full control over the pulse length. We do not use a PWM signal because it relies on a system that simulates analogue outputs by switching on and off at very fast frequencies. This may be a hindrance to biological publishing.

### 2.3 Amplitude modulation

**Constraint.** The user must be able to send modulated actinic light, for example a sinusoidal waveform.

**Options.** PWM, or an analogue output driving a VCCS.

**Choice.** Analogue output with a VCCS.

**Reason.** An analogue signal is continuous, whereas PWM is not.

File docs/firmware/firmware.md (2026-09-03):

# Firmware

## What It Is

The OpenJTS firmware runs on an **ESP32** (`esp32dev` board) and is built with **PlatformIO** using the **Arduino** framework (see [`platformio.ini`](../../firmware/platformio.ini)). It is a small, non-blocking state machine that listens for text commands over USB serial and, in response, drives the instrument's actinic LED, detector LED, and laser trigger outputs with microsecond-level timing. The desktop application (see [Software Architecture](../software/architecture.md)) is the only intended sender of these commands.

---

## Source Layout

The firmware folder contains the main.cpp file, a plateformio.ini file and a lib folder.
Each folder is composed of
-a header file (.h) that is used for :...
-a C++ file (.cpp) that is used for :... 

```
firmware/
├── platformio.ini              # esp32dev / Arduino framework
├── src/main.cpp                # This file containes : setup()/loop(), pin init, state dispatch
└── lib/
    ├── config/                 # This file containes :
    ├── system_context/         # This file containes :
    ├── serial_comm/            # This file containes :
    ├── hardware/               # This file containes :
    └── states/                 # This file containes :
```

## Hardware Pins

Pin assignments live in [`lib/config/config.h`](../../firmware/lib/config/config.h).

| Pin | GPIO | Role |
|---|---|---|
| `TriggPin` | 12 | Digital trigger pulses bracketing a detection event (e.g. for synchronizing an external DAQ) |
| `actinicDacPin` | 26 | Actinic light level — DAC output (`DAC_CHANNEL_2`) |
| `detectorDacPin` | 25 | Detector LED — plain digital GPIO, driven fully on/off |
| `laserChannel_open` | 18 | Laser channel "open" trigger pulse |
| `laserChannel_start` | 19 | Laser channel "start" trigger pulse |

`TriggPin` was deliberately moved from GPIO25 to GPIO12 to free GPIO25 for the detector LED, which needs the GPIO matrix's push-pull output stage for sharp edges. On boot, `setup()` maxes out the pad drive strength on all four pulse pins (`GPIO_DRIVE_CAP_3`) so their edges stay sharp even when the actinic LED's current draw sags the rail, and immediately forces the actinic output to a true 0 V so nothing is left floating before the first command arrives.

### Actinic level (DAC quirk)

The ESP32's DAC has a non-zero floor voltage at code 0 (tens to hundreds of mV) — enough to keep a sensitive actinic LED driver visibly lit. `writeActinicLevel()` (in [`lib/states/states.cpp`](../../firmware/lib/states/states.cpp)) works around this: a value of 0 disables the DAC channel and drives the pin as a plain digital `LOW`, while any other value uses `dacWrite()` (8-bit, 0–255).

---

## Serial Protocol

Every message is framed as `<...>`: a `startMarker` (`<`) resets the input buffer, an `endMarker` (`>`) marks the message complete. Framing and buffering are handled by [`readSerial()`](../../firmware/lib/serial_comm/serial_comm.cpp), which is polled once per `loop()` iteration and is non-blocking.

The first character of a framed message selects the command; markers are defined in `config.h`:

| Marker | Char | Meaning |
|---|---|---|
| `continuesMarker` | `#` | Enter continuous-flash mode; digits after it set the flash interval in ms (e.g. `<#200>`) |
| `constantLightMarker_on` | `O` | Enter constant-light mode; digits after it set the actinic level as a percentage (e.g. `<O75.5>`) |
| `constantLightMarker_off` | `I` | Reserved for turning constant light off — defined but not currently read by the state machine (send `<O0>` instead) |
| `set_LED_intensity` | `S` | While in continuous-flash mode, set detector LED intensity as a percentage (e.g. `<S50>`) |
| `stopMarker` | `X` | Abort — only recognized mid-wait during a sequence delay |
| *(digit)* | `0`–`9` | Start a sequence-acquisition message (see below) |

---

## State Machine

`ctx.state` (in [`lib/system_context/system_context.h`](../../firmware/lib/system_context/system_context.h)) drives a `switch` in `loop()`. Handlers live in [`lib/states/states.cpp`](../../firmware/lib/states/states.cpp).

- **IDLE** (`handleIdle`) — the default/resting state. Waits for a framed message and dispatches based on its first character: `#` → CONTINUES_FLASH, `O` → CONSTANT_LIGHT, a leading digit → SEQUENCE_ACQUISITION.
- **CONTINUES_FLASH** (`handleContinuesFlash`) — repeatedly calls `detection_trigger()` once per second. An `S` message updates the (currently unused by hardware, see below) detector intensity setting; any other message returns to IDLE.
- **CONSTANT_LIGHT** (`handleConstantLight`) — parses the percentage from the buffer, converts it to a DAC code, calls `writeActinicLevel()`, and returns to IDLE. This is a one-shot: the state exists only to interpret the `O` message's payload before falling back to IDLE.
- **SEQUENCE_ACQUISITION** (`handleSequence`) — parses and executes a compact sequence mini-language from the buffer, then returns to IDLE.

### Sequence mini-language

`handleSequence()` scans the message character by character:

| Token | Effect |
|---|---|
| `D` | Fire `detection_trigger()` |
| `L` | Fire `laser_trigger()` |
| `<number>!` | Set the actinic level to `<number>`% immediately (no delay) |
| `<number>` (no `!`) | Wait `<number>` ms, abortable — if an `<X>` message arrives during the wait, the sequence stops immediately |

Waits are implemented by `waitAbortable()`, which sleeps in 1 ms chunks and polls serial between each one, so a stop command can interrupt a long wait instead of blocking behind a single `delayMicroseconds()` call. After the sequence ends (normally or via abort), the actinic output is restored to `currentActinicPWM` and the state returns to IDLE.

---

## Trigger Timing

Both trigger routines live in [`lib/hardware/hardware.cpp`](../../firmware/lib/hardware/hardware.cpp) and use direct `GPIO_SET`/`GPIO_CLR` register writes (defined in `config.h`) rather than `digitalWrite()`, for speed.

- **`detection_trigger()`** — pulses `TriggPin` high for 2 µs, then holds `detectorDacPin` high for 18 µs (lighting the detector LED), then pulses `TriggPin` high for 2 µs again before clearing the detector LED. The two `TriggPin` edges bracket the detection window for an external DAQ.
- **`laser_trigger()`** — pulses `laserChannel_open` high for 10 µs, waits 160 µs, then pulses `laserChannel_start` high for 10 µs.

---

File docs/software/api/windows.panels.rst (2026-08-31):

windows.panels
==============

.. automodule:: windows.panels

.. rubric:: Modules

.. autosummary::
   :toctree:
   :recursive:

   background_light
   calibration
   experiment_metadata
   sample_container
   saturating_pulse
   sequence_history
   sequence_library
   settings

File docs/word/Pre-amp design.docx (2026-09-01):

# Transimpedance amp design

The transimpedance amp is one of the critical building blocks of the JTS and one of the most difficult to design. It's in charge of converting the current coming out of the photodiode into a voltage readable by the DAQ device. Many designs are possible.

## Constraints

The design of the transimpedance amp is a subtle balance between gain, bandwidth and linearity, which are determined by the type of light signal received. The main problem comes from the range of light intensities to measure. Indeed, for a fluorescence measurement, the signal can be of the order of volts whereas in spectro measurement it can be only a few 10s of microvolts. In any case we need a bandwidth able to resolve 20 µs pulses with a decent gain.

From [Photodiode](optical-transmission.md#photodiode), our photodiode is a Hamamatsu Si PIN [S ….. BQ], reverse-biased at 48 V, giving a terminal capacitance **Cd ≈ 47 pF** and negligible dark current (a few nA).

A good starting point on transimpedance amp designs is here: https://www.digikey.fr/fr/articles/how-to-design-stable-transimpedance-amplifiers-automotive-medical-systems

### Bandwidth target

To resolve a 20 µs pulse without excessive rounding of the edges, the amplifier's rise time should be roughly 1/15 to 1/20 of the pulse width:

```

t_r ≈ 20 µs / 17 ≈ 1.2 µs

f_-3dB = 0.35 / t_r ≈ 300 kHz

```

We take **300 kHz** as the minimum closed-loop bandwidth for every gain range.

### Stability of a TIA

A photodiode's capacitance (Cd) forms a pole with the feedback resistor (Rf) that erodes phase margin and causes peaking/ringing if left uncompensated. A feedback capacitor (Cf) in parallel with Rf must be added to restore stability. The standard design equations (from the article above) are:

```

f_-3dB ≈ sqrt( GBW / (2π · Rf · Cd) )

Cf ≈ sqrt( Cd / (2π · Rf · GBW) )

```

where GBW is the op-amp's gain-bandwidth product. These give a starting point; final Cf values need to be trimmed on the bench, since stray/PCB/relay capacitance also loads the feedback node.

## Options

### Single fixed-gain TIA

**Constraint:** cover both the volt-level fluorescence signal and the microvolt-level spectro signal with one gain setting.

**Problem:** the two regimes are 5–6 decades apart. A single Rf either saturates on bright signals or buries dim signals in noise. This is ruled out.

### Log amplifier

Compresses the whole dynamic range into a single output span. Rejected: log amps trade away linearity, which the constraints explicitly require, and they complicate the differential (measurement − reference) math used throughout the JTS ([Optical Transmission](optical-transmission.md)).

### Switched-gain TIA (auto-ranging)

A single transimpedance stage whose feedback resistor Rf is switched between decades (e.g. 1 kΩ → 10 MΩ) to match the expected signal level, selected either by the user or automatically by the firmware before each flash sequence.

**Choice: this is the design we use.**

## Final design

### Architecture

```

Photodiode (Cd ≈ 47 pF, reverse-biased 48 V)

│

├── Rf(n) ── Cf(n) (n = selected range, in parallel)

│

── inverting input of op-amp ──── output ── RC anti-alias filter ── ADC

│

non-inverting input → ground (or bias reference)

```

Rf is switched via reed relays rather than CMOS analog switches: at the multi-megohm ranges, a CMOS switch's off-leakage and parasitic capacitance sit directly on the high-impedance summing node and corrupt the gain/offset, whereas a reed relay contributes negligible leakage and only a couple of pF. Range switching only needs to happen between flash sequences, so the relay's millisecond-scale settling time is not a constraint.

### Op-amp choice

The summing node is high-impedance (up to ~10 MΩ), so the op-amp needs:

- Low input bias current (it multiplies directly by Rf into an offset/dark-current-like error)

- Low input capacitance (adds to Cd and eats into bandwidth)

- High GBW (needed to hit 300 kHz bandwidth at the highest Rf)

- Low voltage noise (this is the SNR-critical stage for the spectro range)

**Choice: ADA4817-1** (FET input, GBW ≈ 1 GHz, en ≈ 4 nV/√Hz, Ib in the low pA range). OPA657 is a reasonable substitute with similar GBW if availability is a problem, at the cost of somewhat higher input bias current.

Note the **AD797** already used in the [VCCS design](VCCS-design.md) is *not* suitable here — it's a low-noise bipolar-input part with bias current in the nA range, which is fine driving a low-impedance sense resistor but would swamp a multi-megohm TIA node with offset error.

### Worked ranges

Using GBW = 1 GHz and Cd = 47 pF in the equations above:

| Rf | f_-3dB (uncompensated calc) | Notes |

| 1 kΩ | ~58 MHz | bandwidth is op-amp/output-filter limited, not Cd-limited; add explicit Cf for noise-bandwidth control anyway |

| 10 kΩ | ~18 MHz | same |

| 100 kΩ | ~5.8 MHz | same |

| 1 MΩ | ~1.8 MHz | comfortably above 300 kHz target |

| 10 MΩ | ~580 kHz | still above 300 kHz target, this is the practical ceiling for this op-amp/Cd combination |

10 MΩ is taken as the top of the range — it clears the 300 kHz requirement with margin while keeping bias-current-induced offset (10 MΩ × low-pA Ib ≈ tens of µV) small relative to the smallest signals we intend to resolve. Going further (e.g. 60 MΩ, the theoretical stability limit for this op-amp) buys no real headroom and makes offset and relay-leakage errors worse, so it's not used.

Cf for each range should be set per the sqrt formula above as a starting point and then tuned on the bench/in SPICE against a pulse or square-wave input, watching for peaking (Cf too small) vs. sluggishness (Cf too large) — final values depend on layout parasitics that aren't predictable by hand calculation.

### Downstream filtering

A single-pole RC anti-aliasing filter (~500 kHz–1 MHz corner) follows the TIA before the ADC, to band-limit noise from the low-gain ranges (which have much more raw bandwidth than needed) without touching the 300 kHz signal content.

### Layout notes

- Guard ring the inverting input node (Rf pads, relay contacts, op-amp pin) with a low-impedance ground/guard trace driven near the same potential, to intercept leakage currents that would otherwise flow into the high-impedance node — this matters most at the 1–10 MΩ ranges.

- Keep Rf and Cf physically close to the op-amp to minimize stray capacitance that isn't accounted for in the Cf calculation.

- Keep the photodiode's reverse-bias supply (48 V) well separated/filtered from the TIA's analog supply and ground to avoid injecting switching noise into the summing node.

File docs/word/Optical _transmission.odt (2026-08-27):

## Optical transmission

### Background

The first JTS designs used xenon flash lamps to produce the detection flashes. Xenon lamps give short and powerful flashes, but they are very unstable from one flash to the next. This is a real problem in differential spectroscopy: the absorption changes being measured are small, so fluctuations in the intensity of the detection light are enough to hide them.

The solution was to send the same flash to two channels and to normalise one against the other. One channel holds the sample (the measurement channel); the other holds only a shutter (the reference channel), used to balance the light intensity between the two. At each time point, the reference is subtracted from the measurement and the result is divided by the reference:

signal = (I_measurement − I_reference) / I_reference

Any variation common to both channels therefore cancels out.

Detection flashes

### Constraint

The detection flashes must be stable, powerful and synchronised between the two channels.

Options

Two optical designs have been used to bring the same detection light to both channels:

- a semi-reflecting mirror (beam splitter)
- a Y-shaped optical fibre

Each has advantages and drawbacks.

A third option is to use two seperate LEDs controled by the same circuit. The normalisation then only rejects the supply and driver-level noise but not the LED noise. That's probably fine given how stable LEDs are.

### Choice

Two modern LEDs, one per channel, driven by the same circuit.

### Reasons

Modern LEDs are far more stable than xenon lamps and are powerful enough for the measurement, so the flash no longer has to be split from a single source.The actinic light is not transmitted through the fiber optics and you don’t have to buy a super expensive fiber optic.

Light filtres

Contraints

The detection flashes and actinic flashes should be filtered out correctly acording to the experiment the user wants to do.

Options :

For the detection light the previous JTS models use either :

- A monochromateur
- A varispec
- A choosable detection light array where many colors are available
- Flat round filters
- Double linear filter

Choice

For the OpenJTS we will use flat round filters

Reasons

This the cheapest and simplest way to filter out the detection light.

Photodiode

Constraint

We need to precisely measure light intensity from 20µs pulses with the best SNR.

Options

When choosing a photodiode many attributes come in to play:

- Photosensitive area determines how many photons will be captured. The bigger the surface, the more signal there will be
- Spectral response range Needs to cover the entirety of the desired spectral range
- Terminal capacitance determines the response speed, a lower capacitance increase the bandwidth
- Reverse voltage Reverse voltage lowers the terminal capacitance and increases bandwidth and dark noise
- Dark current current noise when the photodiode is in the dark

Many different models are possible.

Choice

We used the Hamatasu Si PIN photodiode [S ….. BQ] reversed bias at 48v.

Reasons

This model has one of the largest areas, a good spectral response range and a low terminal capacitance. In addition, with a 48v reverse voltage drops the terminal capacitance to 47pF witch suits well with our 20µs pulses. The dark current of a few nA is negligible.

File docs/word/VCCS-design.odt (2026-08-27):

VCCS design

For this version of the JTS we are using the analog output of an ADC and a VCCS to control the actinic LED.

What is a VCCS?

VCCS stands for Voltage Controled Current Source. As the name suggests, it is a electronical circuit that lets you control a current proportionally to a voltage regardless of what load is connected to the output.

Why a VCCS?

We are using LED to produce actinic and detection light. However, a LED intensity is not linear with Voltage but with Current.

It is possible to either use a matrix of resistors and transistors to select light intensity where each resistor determines the current going through the LED.

Or we can use the analog output of an ADC, that outputs a voltage (from 0 to 10v with 32000 possibilities in between) and a VCCS. This lets the user select a large selection of light intensities with a simple circuit and software controlling the ADC. This design also permits actinic light patterns such as sine waves or anything else.

Alternatively, we can also use a PWM with a VCCS but this will be explored on a future version.

How to build a VCCS?

A simple VCCS is composed of the following components:

An differential or op amp, a MOSFET or BJT, a LED (or any current driven load) and a sense resistor (or shunt resistor).

R1 and R2 are optional.

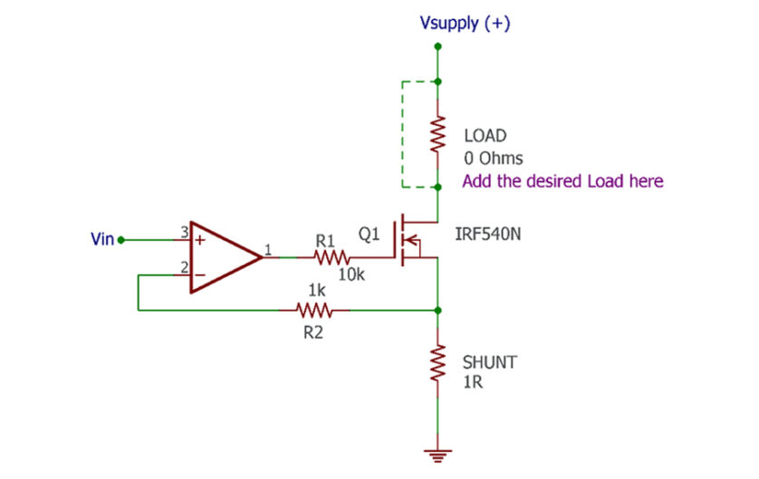
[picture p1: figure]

How does it work?

As it is with any amplifier, the circuit continuously compares the input voltage to the feedback loop.

The input voltage is regulated by the ADC in our case.

The feedback voltage is proportional to current going through it (V = I x R)

Any difference between the two will be corrected by the op amp.

The difference signal drives a transistor that acts as the variable current valve

The op-amp drives the transistor gate/base until the voltage across R_sense equals V_in, so:

I_out = V_in / R_sense

Important notes:

The LED supply should be powerful enough to drive the LED and Sense resistor.

For a given I_out, smaller R_sense gives a small V_sense and so a bigger SNR: For example, if you want 100 mA and R_sense = 1 Ω V_sense = 100 mV. But if R_sense = 0.01 Ω V_sense = only 1 mV.

For a given V_in, bigger R_sense gives better control but power loss.

Final Design for the JTS:

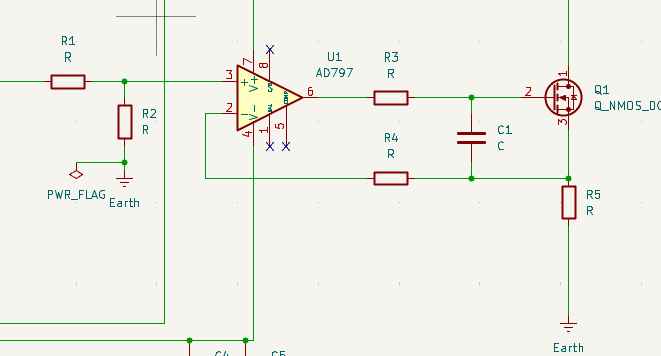
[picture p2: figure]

There are some differences with the basic design.

Voltage devider:

Constraints:

First of all, we are using a 48v generator with a 38v LED. The MOSFET uses up around 1-2V. This leaves around 8 volts of headroom for the sense resistor. If we send a 10v signal to V_in, the signal will saturate at 8v. Practically, during contruction, we have observed a saturation level for a signal around 3-4V.

Options:

We can either use a larger power supply or add a voltage devider on analog output to lower V_in.

Choice:

We are using a voltage devider that lowers the V_in by around 5. So 10v becomes 2v.

Reasons:

Both solutions are possible but we have chosen to use a voltage devider because it is simple to make and can be adapted to any power supply.

MOSFET :

The transistor being used is a N type Power MOSFET. It needs to be able to withstand at least 2 amps of current and needs a fast sw²itching time. The IRF540N fits perfectly for this circuit.

OP amp:

We are using the AD797 for this circuit because of its low voltage noise. We had many in stock at the time of making the circuit. It can be substituted for another op amp.

Sense resistor:

The sense resistor should be small enough to deliver enough power to actinic light and big enough so that the output signal has a good SNR. The maximum output should be saturating but there should also be enough low levels lights to perform certain experiments.

We have chosen 30ohms for this resistor because it fits well with our constraints.

C1 condensor

This condenser was added to filter out high frequency noise observed on the photodiode. These high frequency noises are probably due to the high impedance of the MOSFET gate that acts like a capacitance. Therefore, the MOSFET can open and close in a unpredictable manner. This problem was easily solved by adding a small capacitor between Gate and Source, filtering out large frequency noise.

R3 and R4 resistors

These resistors are not mandatory but they help with stability and avoid ringing.

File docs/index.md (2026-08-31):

# OpenJTS

Welcome to the documentation for OpenJTS, an open hardware version of the Joliot Type Spectrophotometer (JTS). Here you'll find everything needed to build, run and contribute to the project: technical notes, construction instructions and manuals covering the hardware, software and firmware.

My image

## Purpose

The OpenJTS is designed for measuring light-induced transient signals in photosynthesis research: ECS, Phi PSII, and related fluorescence and spectroscopy protocols.

This version was designed as an open alternative to commercial JTS instruments (such as the JBeamBio JTS). With modest skills and budget, interested labs can build their own instrument, and anyone is welcome to contribute to its development.

Compared to previous versions, OpenJTS offers:

- A new user interface written in Python
- A greater number of actinic and detection light levels
- Two independent detection LEDs, replacing the Y fibre optic used previously
- A design optimized for flat samples

## Where to start

The full step-by-step build instructions are available in the [build manual](hardware/build/full-build-manual.md). Note that there are several separate instruction manuals, one for each independent part of the instrument, to keep things clear.

## Licence

OpenJTS is released under the [Apache License 2.0](../LICENSE).

```{toctree}
:maxdepth: 2
:caption: Documentation

hardware/index
software/index
firmware/firmware
```

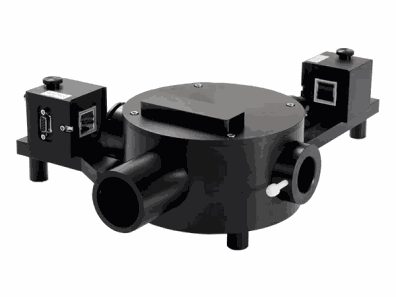
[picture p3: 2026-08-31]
docs/assets/img/JTS150_002.png

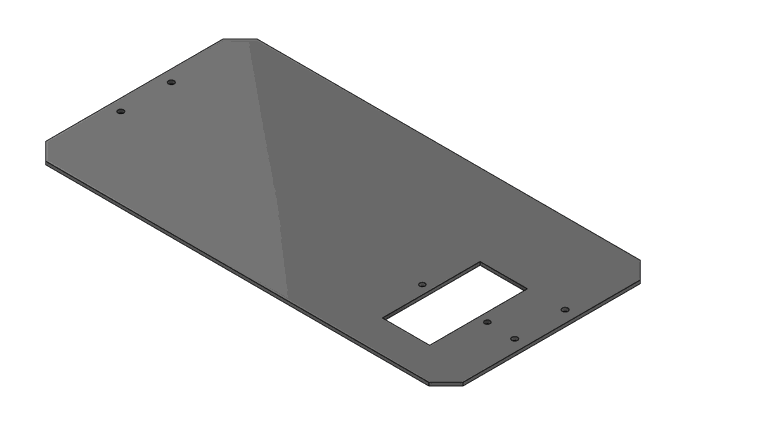
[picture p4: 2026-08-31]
docs/assets/img/JTS-Back_panel.png

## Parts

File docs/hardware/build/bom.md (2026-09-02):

# Bill of Materials

**Total: 2540**

---

## Electronics

| Component | Quantity | Price per unit | Reference |
|---|---|---|---|
| Instrument case | 1 | 175 | [Link](https://fr.rs-online.com/web/p/boitiers-d-instrumentation/7694914) |
| 15v linear power supply | 1 | 89 | [Link](https://fr.rs-online.com/web/p/alimentations-lineaires/1063850?gb=a) |
| 15v switching power supply | 1 | 50 | [Link](https://fr.rs-online.com/web/p/alimentations-a-decoupage/6641474) |
| 48v switching power supply | 1 | 44 | [Link](https://fr.rs-online.com/web/p/alimentations-a-decoupage/6447051) |
| MCC USB-1808X | 1 | 1040 | [Link](https://digilent.com/shop/mcc-usb-1808x-high-speed-high-precision-simultaneous-usb-daq-device/) |
| esp32 dev board | 1 | 15 | [Link](https://fr.rs-online.com/web/p/outils-de-developpement-pour-microcontroleurs/2863991) |
| coax cables BNC | 4 | 24 | [Link](https://fr.rs-online.com/web/p/cables-coaxiaux/2843792) |
| Power cables | 1 | 20 | [Link](https://fr.rs-online.com/web/p/cables-de-controle/2369230) |
| Sub-d9 male | 10 | 8 | [Link](https://fr.rs-online.com/web/p/connecteurs-sub-d/7659441) |
| Sub-d9 femelle | 7 | 8 | [Link](https://fr.rs-online.com/web/p/connecteurs-sub-d/5443749) |
| coax connectors femelle | 6 | 6 | [Link](https://fr.rs-online.com/web/p/connecteurs-coaxiaux/5464910) |
| AD797 | 3 | 20 | [Link](https://www.digikey.fr/fr/products/detail/analog-devices-inc/AD797ANZ/751113) |
| MOSFET IRF540N | 1 | 1 | [Link](https://fr.rs-online.com/web/p/transistors-mosfet/9148154) |
| MOSFET IRLZ44N | 2 | 1 | [Link](https://fr.rs-online.com/web/p/transistors-mosfet/5410086) |
| Resistors | | | |
| Capacitors | | | |
| Molex KK 396 x 8 male | 1 | 5 | [Link](https://fr.rs-online.com/web/p/embases-circuits-imprimes/6795704) |
| Molex KK 396 x 8 femelle | 1 | 5 | [Link](https://fr.rs-online.com/web/p/boitiers-de-connecteurs-pour-circuits-imprimes/6795082) |
| Crimp terminal | 1 | 17 | [Link](https://fr.rs-online.com/web/p/contacts-a-sertir/0467598) |
| Different power cables | 1 | 18 | [Link](https://fr.rs-online.com/web/p/fils-de-cablage/3836054) |
| esp32 support board | 1 | 10 | [Link](https://fr.rs-online.com/web/p/outils-de-developpement-pour-microcontroleurs/2863992) |

## Structure

| Component | Quantity | Price per unit | Reference |
|---|---|---|---|
| 25 mm Square Construction Rails | 4 | 17 | [Link](https://www.thorlabs.com/25-mm-optical-construction-rails?pn=XE25L225%2FM&tabName=Overview) |
| Construction Cubes for 25 mm Rails | 2 | 5 | [Link](https://www.thorlabs.com/25-mm-optical-construction-rails?pn=XE25L225%2FM&tabName=Overview) |
| Elbow Plates for 25 mm Rails | 2 | 14 | [Link](https://www.thorlabs.com/25-mm-optical-construction-rails?pn=XE25L225%2FM&tabName=Overview) |
| Drop-In T-Nuts for XE Series Rails | 1 | 33 | [Link](https://www.thorlabs.com/t-nuts-and-screws-for-25-mm-50-mm-75-mm-rails?tabName=Overview) |
| Low-Profile Channel Screws | 1 | 18 | [Link](https://www.thorlabs.com/t-nuts-and-screws-for-25-mm-50-mm-75-mm-rails?tabName=Overview) |
| M3 spacer | 1 | 15 | [Link](https://fr.rs-online.com/web/p/entretoises-filetees/0606686) |

## PCBs

You can order the following PCB components at a PCB manufacturer such as [Link](https://jlcpcb.com/).

| Component | Quantity | Price per unit | Reference |
|---|---|---|---|
| Preamp PCB | 2 | 20 |  |
| LED controler PCB | 1 | 2 |  |
| Actinic LED PCB | 1 | 1 |  |
| Front panel PCB | 1 | 2 | |

## CNC parts

You can order the following CNC components at a CNC manufacturer such as [Link](https://jlccnc.com/).

| Component | Quantity | Price per unit | Image |
|---|---|---|---|
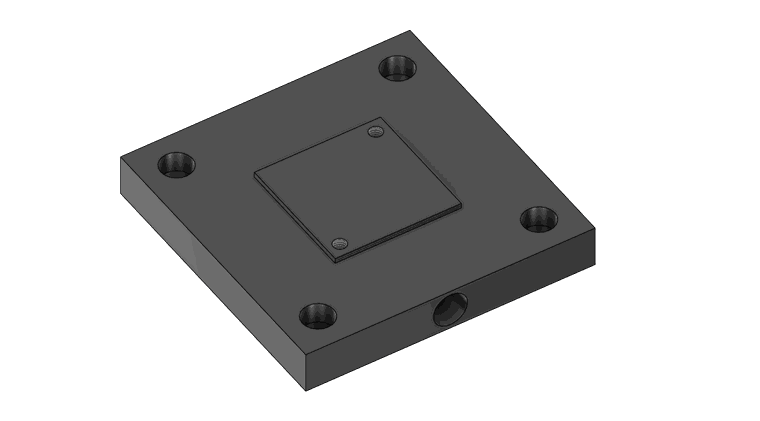
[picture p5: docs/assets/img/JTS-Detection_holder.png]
| Detection LED holder | 2 | 18 |  |
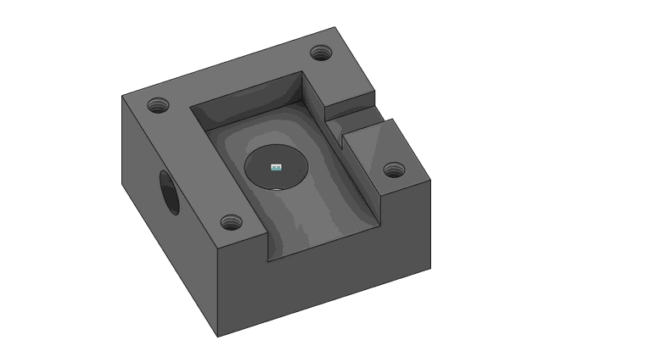
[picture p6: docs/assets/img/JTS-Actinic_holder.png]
| Actinic LED holder | 2 | 27 |  |
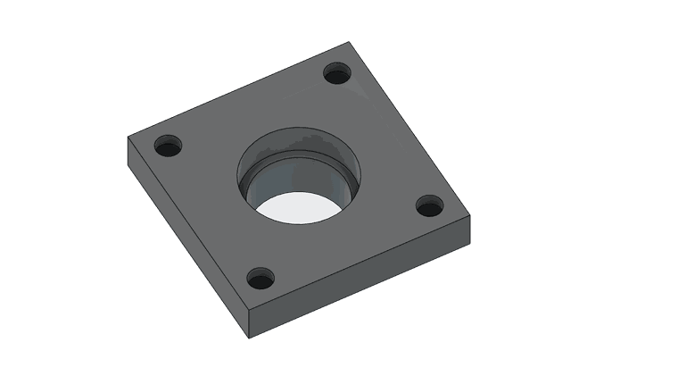
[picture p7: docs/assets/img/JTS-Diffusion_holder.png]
| Diffusion holder | 2 | 30 |  |
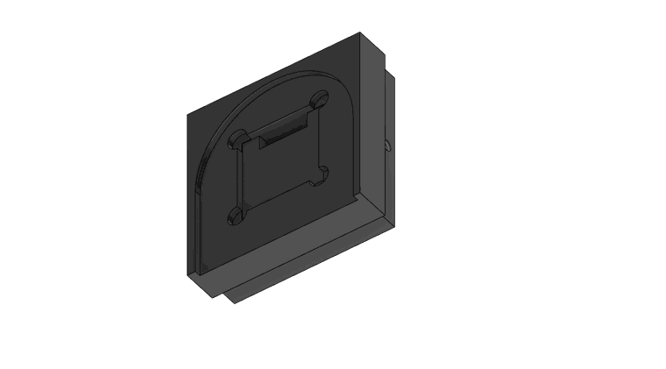
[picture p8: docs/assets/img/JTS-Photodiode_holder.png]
| Photodiode holder | 2 | 35 |  |
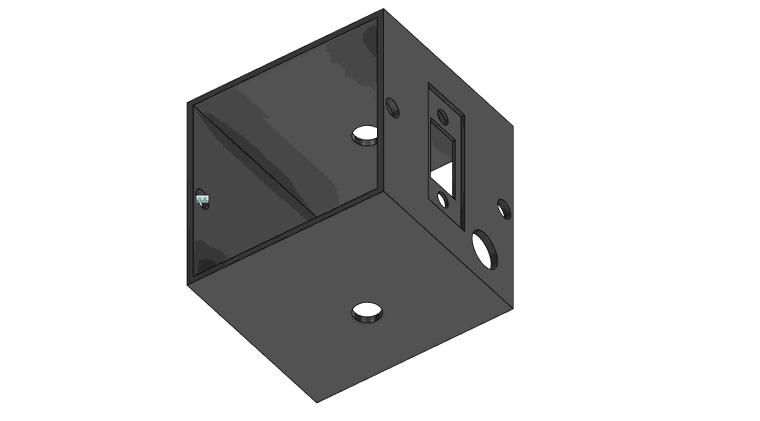
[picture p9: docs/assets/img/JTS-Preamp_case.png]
| preamp case | 2 | 65 |  |
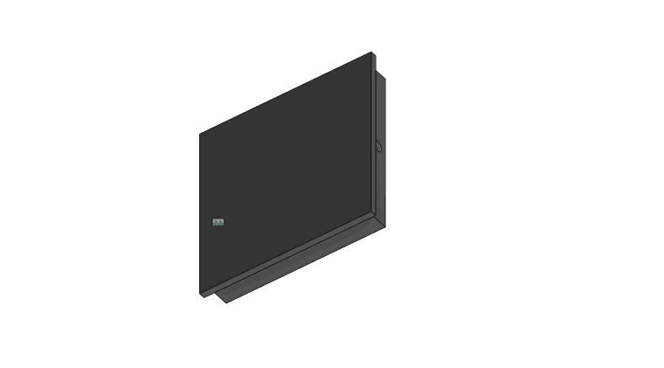
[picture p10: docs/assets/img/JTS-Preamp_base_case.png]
| preamp case base | 2 | 18 |   |
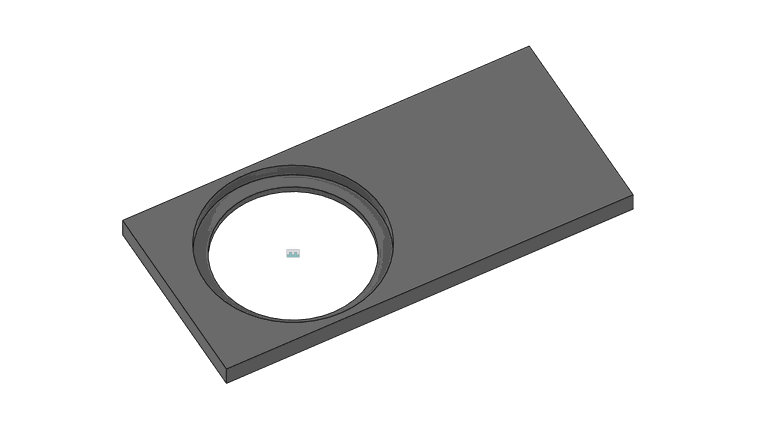
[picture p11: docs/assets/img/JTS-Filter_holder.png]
| Filter holder | 2 | 6 |   |
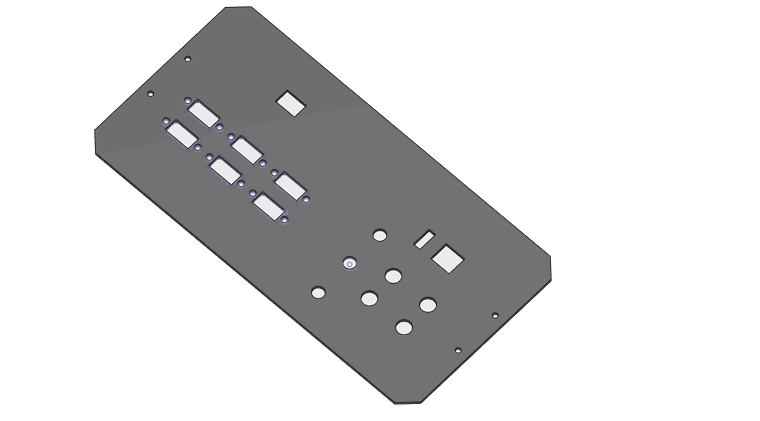
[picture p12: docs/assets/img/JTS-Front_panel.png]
| Front panel | 2 | 18 |   |
| Sample holder top | 1 | 28 | My image  |
| Sample holder bottom | 1 | 18 | My image  |

## Optics

| Component | Quantity | Price per unit | Reference |
|---|---|---|---|
| Filter 520 25mm | 1 | | |
| Filter 480 25mm | 1 | | |
| filter RGB | 1 | | |
| Filtre 720 | 1 | | |
| Diffuseur 25mm | 2 | | |
| Photodiode | 2 | | [Link](https://www.hamamatsu.com/eu/en/product/optical-sensors/photodiodes/si-photodiodes/S3204-08.html) |
| Actinic LED red | 8 | 3 | [Link](https://www.mouser.fr/fr/ProductDetail/Cree-LED/XEGARD-H0-0000-000-000000S5001) |
| Detection LED | 2 | | |
| window | 1 | | |

## Tools
-Soldering unit
-Screw drivers and spanners
-Pliers
-Small drill

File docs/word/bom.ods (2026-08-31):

 | Component | Quantity | Price per unit | Reference
Electronics
 | Instrument case | 1 | 175 | https://fr.rs-online.com/web/p/boitiers-d-instrumentation/7694914
 | 15v linear power supply | 1 | 89 | https://fr.rs-online.com/web/p/alimentations-lineaires/1063850?gb=a
 | 15v switching power supply | 1 | 50 | https://fr.rs-online.com/web/p/alimentations-a-decoupage/6641474
 | 48v switching power supply | 1 | 44 | https://fr.rs-online.com/web/p/alimentations-a-decoupage/6447051
 | MCC USB-1808X | 1 | 1040 | https://digilent.com/shop/mcc-usb-1808x-high-speed-high-precision-simultaneous-usb-daq-device/
 | esp32 dev board | 1 | 15 | https://fr.rs-online.com/web/p/outils-de-developpement-pour-microcontroleurs/2863991
 | coax cables BNC | 4 | 24 | https://fr.rs-online.com/web/p/cables-coaxiaux/2843792
 | Power cables | 1 | 20 | https://fr.rs-online.com/web/p/cables-de-controle/2369230
 | Sub-d9 male | 10 | 8 | https://fr.rs-online.com/web/p/connecteurs-sub-d/7659441
 | Subd-d9 femelle | 7 | 8 | https://fr.rs-online.com/web/p/connecteurs-sub-d/5443749
 | coax concectors femelle | 6 | 6 | https://fr.rs-online.com/web/p/connecteurs-coaxiaux/5464910
 | AD797 | 3 | 20 | https://www.digikey.fr/fr/products/detail/analog-devices-inc/AD797ANZ/751113
 | MOSFET IRF540N | 1 | 1 | https://fr.rs-online.com/web/p/transistors-mosfet/9148154?matchtype=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
 | MOSFET IRLZ44N | 2 | 1 | https://fr.rs-online.com/web/p/transistors-mosfet/5410086
 | Resistors
 | Capacitors
 | Molex KK 396 x 8 male | 1 | 5 | https://fr.rs-online.com/web/p/embases-circuits-imprimes/6795704
 | Molex KK 396 x 8 femelle | 1 | 5 | https://fr.rs-online.com/web/p/boitiers-de-connecteurs-pour-circuits-imprimes/6795082
 | Crimp terminal | 1 | 17 | https://fr.rs-online.com/web/p/contacts-a-sertir/0467598
 | Different power cables | 1 | 18 | https://fr.rs-online.com/web/p/fils-de-cablage/3836054
 | esp32 support board | 1 | 10 | https://fr.rs-online.com/web/p/outils-de-developpement-pour-microcontroleurs/2863992
Structure
 | 25 mm Square Construction Rails | 4 | 17 | https://www.thorlabs.com/25-mm-optical-construction-rails?pn=XE25L225%2FM&tabName=Overview
 | Construction Cubes for 25 mm Rails | 2 | 5 | https://www.thorlabs.com/25-mm-optical-construction-rails?pn=XE25L225%2FM&tabName=Overview
 | Elbow Plates for 25 mm Rails | 2 | 14 | https://www.thorlabs.com/25-mm-optical-construction-rails?pn=XE25L225%2FM&tabName=Overview
 | Drop-In T-Nuts for XE Series Rails | 1 | 33 | https://www.thorlabs.com/t-nuts-and-screws-for-25-mm-50-mm-75-mm-rails?tabName=Overview
 | Low-Profile Channel Screws | 1 | 18 | https://www.thorlabs.com/t-nuts-and-screws-for-25-mm-50-mm-75-mm-rails?tabName=Overview
 | M3 spacer | 1 | 15 | https://fr.rs-online.com/web/p/entretoises-filetees/0606686
PCBs
 | Preamp PCB | 2 | 20 | https://jlcpcb.com/
 | LED controler PCB | 1 | 2 | https://jlcpcb.com/
 | Actinic LED PCB | 1 | 1 | https://jlcpcb.com/
 | Front panel PCB | 1 | 2 | https://jlcpcb.com/
CNC parts
 | Detection LED holder | 2 | 18 | https://jlccnc.com/
 | Actinic LED holder | 2 | 27 | https://jlccnc.com/
 | Diffusion holder | 2 | 30 | https://jlccnc.com/
 | Photodiode holder | 2 | 35 | https://jlccnc.com/
 | pream case | 2 | 65 | https://jlccnc.com/
 | preamap case base | 2 | 18 | https://jlccnc.com/
 | Filter holder | 2 | 6 | https://jlccnc.com/
 | Front panel | 2 | 18 | https://jlccnc.com/
 | Sample holder top | 1 | 28 | https://jlccnc.com/
 | Sample holder bottom | 1 | 18 | https://jlccnc.com/
Optics
 | Filter 520 25mm | 1
 | Filter 480 25mm | 1
 | filter RGB | 1
 | Filtre 720 | 1
 | Diffuseur 25mm | 2
 | Photodiode | 2 |  | https://www.hamamatsu.com/eu/en/product/optical-sensors/photodiodes/si-photodiodes/S3204-08.html
 | Actinic LED red | 8 | 3 | https://www.mouser.fr/fr/ProductDetail/Cree-LED/XEGARD-H0-0000-000-000000S5001?qs=i8QVZAFTkqQ96EIj8gzjPQ%3D%3D
 | Detection LED | 2
 | window | 1
 |  |  | 2540

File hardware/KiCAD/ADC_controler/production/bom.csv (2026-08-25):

Designator | Footprint | Quantity | Value | LCSC Part #
C1, C2, C3, C4, C5, C6, C7 | CP_Radial_D8.0mm_P5.00mm | 7 | C
J1 | Molex_KK-396_5273-08A_1x08_P3.96mm_Vertical | 1 | Power in
J4 | TerminalBlock_Phoenix_MKDS-1,5-2-5.08_1x02_P5.08mm_Horizontal | 1 | ADC in
J5 | Molex_KK-396_5273-08A_1x08_P3.96mm_Vertical | 1 | Power out
J6 | TerminalBlock_Phoenix_MKDS-1,5-2-5.08_1x02_P5.08mm_Horizontal | 1 | Analog GND
J7 | TerminalBlock_Phoenix_MKDS-1,5-2-5.08_1x02_P5.08mm_Horizontal | 1 | Saturating Pulse
J8 | TerminalBlock_Phoenix_MKDS-1,5-2-5.08_1x02_P5.08mm_Horizontal | 1 | ESP32 in
Q1 | TO254P1054X469X1930-3 | 1 | Actinic
Q2 | TO254P1054X469X1930-3 | 1 | ADC D
Q3 | TO254P1054X469X1930-3 | 1 | SAturating
Q4 | TO254P1054X469X1930-3 | 1 | ESP32 D
R1, R2, R3, R4 | R_Axial_DIN0204_L3.6mm_D1.6mm_P7.62mm_Horizontal | 4 | R
R5, R7, R8 | R_Axial_DIN0309_L9.0mm_D3.2mm_P15.24mm_Horizontal | 3 | R
R6, R9 | R_Axial_DIN0204_L3.6mm_D1.6mm_P7.62mm_Horizontal | 2 | 100
U1 | DIP-8_W7.62mm_Socket_LongPads | 1 | AD797

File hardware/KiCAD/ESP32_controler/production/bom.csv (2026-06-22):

Designator | Footprint | Quantity | Value | LCSC Part #
+15V1, +48V1, LASER-A1, LASER-B1 | TerminalBlock_Phoenix_MKDS-1,5-2-5.08_1x02_P5.08mm_Horizontal | 4 | Conn_01x02_Pin
J1, J2 | PinSocket_1x15_P2.54mm_Vertical | 2 | Conn_01x15
Q1, Q2, Q3 | TO-220-3_Vertical | 3 | IRF540N
R1, R3, R4 | R_Axial_DIN0309_L9.0mm_D3.2mm_P15.24mm_Horizontal | 3 | 100
R2 | R_Axial_DIN0309_L9.0mm_D3.2mm_P15.24mm_Horizontal | 1 | 5
R5, R6 | R_Axial_DIN0309_L9.0mm_D3.2mm_P15.24mm_Horizontal | 2 | R
R7, R8 | R_Axial_DIN0309_L9.0mm_D3.2mm_P15.24mm_Horizontal | 2 | 50
R9 | R_Axial_DIN0309_L9.0mm_D3.2mm_P15.24mm_Horizontal | 1 | 10

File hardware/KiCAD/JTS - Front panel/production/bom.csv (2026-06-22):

Designator | Footprint | Quantity | Value | LCSC Part #
ACTINIC_2, ACTINIC, DETECTION_2, DETECTION, PHOTODIODE_2, PHOTODIODE | DSUB-9_Pins_Vertical_P2.77x2.84mm_MountingHoles | 6 | DE9_Pins_MountingHoles
C1, C2 | CP_Radial_D10.0mm_P5.00mm | 2 | C
D1, D2, D3 | LED_D5.0mm | 3 | LED
J1 | Molex_KK-396_5273-08A_1x08_P3.96mm_Vertical | 1 | Conn_01x08_Pin
R1, R2, R3, R4, R5 | R_Axial_DIN0207_L6.3mm_D2.5mm_P10.16mm_Horizontal | 5 | R

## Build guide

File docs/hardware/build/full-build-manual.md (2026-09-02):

# Full build manual

This presents the full step-by-step instructions to build an OpenJTS. You will first need to order the materials indicated in the [Bill of Materials](bom.md).

Before you start:

- Read through the [Technical notes](../technical-notes/index.md) for the module you are working on — they explain *why* each part is built the way it is, which makes it much easier to spot a mistake during assembly.
- Gather the tools listed at the bottom of the [BOM](bom.md): soldering iron, screwdrivers and spanners, pliers, and a small drill.
- Work on the electronics (preamp PCBs, LED controller, front panel PCB) on an ESD-safe surface. The AD797 and JFET op-amps used in the preamps are sensitive to static discharge.
- The instrument uses a 48 V rail to reverse-bias the photodiodes and drive the detection LEDs. Treat it with the same care as any other line-powered voltage: power down the supplies before touching exposed connections.

*Add photo here*

---

## Assembling the structure

The mechanical structure is built from 25 mm square optical construction rails (Thorlabs XE25 series), joined with construction cubes and elbow plates, and finished with drop-in T-nuts and low-profile channel screws. This rail frame carries the two preamp cases and the LED housings.

1. Cut or order the rails to the lengths required for your layout, and fit the frame using the construction cubes (corners) and elbow plates (right-angle joints).

*Add photo here*

---

## Building the cables

Three families of cable are needed:

- **Coax (BNC) cables** — carry the preamp outputs to the ADC's analog inputs and trigger the laser. Build 4, per the [BOM](bom.md).
- **Sub-D9 cables** — carry power and control signals between the instrument case and the preamp/LED modules.

1. Cut each cable to desired length so runs are neither too tight nor excessively long.
2. Solder or crimp the connectors specified in the [BOM](bom.md) (Sub-D9 male/female, coax connectors) onto each cable. Be carefull to solder the rigth Sub-D9 pins to the righ place.
3. Label both ends of every cable as you build it — with two symmetric channels (measurement/reference) and two LED paths, it is easy to mix up otherwise.

*Add photo here*

---

## Assembling the preamp cases

Each detection channel (measurement and reference) has its own preamp case, so this section is carried out **twice**. The case houses the transimpedance amplifier (TIA) that turns the photodiode's photocurrent into a voltage — see [Transimpedance Amplifier Design](../technical-notes/preamp-design.md) for the full rationale behind the component choices below.

1. Populate the Preamp PCB (JLCPCB order from the [BOM](bom.md)) with the AD797 op-amp(s), feedback resistor/capacitor network, and supporting components as described in [Transimpedance Amplifier Design](../technical-notes/preamp-design.md). 

Note: it is also possible to order the PB fully populated but this will be more expensive and won't be simple to repair if a component fries.

*Add photo here*

2. Place the photodiode on the photodiode holder and solder to the Preamp PCB. Keep the wires as short as possible.

3. Screw the Sub-D9 right angle connector to the preamp case.

4. Close and screw the photodiode holder and preamp case base. 

5. Insert the long M6 srew in the appropriate hole and screw it to the Thorlabs T-nut.

6. Place on structure

*Add photo here*

---

## Assembling the LED cases

The instrument uses two independent light paths: the **detection** LEDs (short, stable flashes used to probe the sample) and the **actinic** LED (the light that drives the physiological change being observed). See [Technical choices: LED control](../technical-notes/LED-control.md) for why each was designed the way it was.

### Detection LED assembly (×2, one per channel)

1. Mount the detection LED onto the **Detection holder**.
2. Solder the Detection LED Sub-D9 power cabler to the the LED. Beware of the posisitve and negative side.

### Actinic LED assembly

1. Populate the **Actinic LED PCB** with the LED array as specified in [LED control](../technical-notes/LED-control.md). Note: if you have access to a SMD oven this is great. 
2. Mount the LED PCB onto the **Actinic holder**(s). 
3. Solder the Actinic LED Sub-D9 power cabler to the the LED PCB. Beware of the posisitve and negative side.

*Add photo here*

*Add photo here*

## Mount the cases

1. Glue the diffuseur to the diffeuseur stage.
2. assemble all 3 stages together with appropriate screws.
3. Insert the long M6 srew in the appropriate hole and screw it to the Thorlabs T-nut.
4. Place on structure.

---

## Building common ground circuit
1. Add cable inserts (the green things that you can screw)

## Installing the power supplies

Three supplies are used:

| Supply | Used for |
|---|---|
| 15 V linear | ±15 V analog rails for the preamp op-amps and the actinic VCCS (see [VCCS Design](../technical-notes/VCCS-design.md)) |
| 15 V switching | Power for actinic LED|
| 48 V switching | Photodiode reverse bias and detection LED driver (see [LED control §1.2](../technical-notes/LED-control.md#12-intensity)) |

1. Mount all three supplies inside the instrument case on standoffs.
2. Wire the inputs of all 3 supplies to the same power line filter.
3. Wire the +15v to a crimp and the 0 to common ground
4. Wire the +48v to a crimp and the 0v  to a crimp
5. Wire the +15v and -15v to a crimp and the 0v to common ground 
*Add photo here*

---

## Installing the front panel PCB

The front panel carries the instrument's external Sub-D9 connectors.

1. Mount the **Front panel** CNC plate onto the front face of the instrument case.
2. Fit the Sub-D9 male/female connectors into their cutouts, referring to the [BOM](bom.md) for connector counts.
3. Populate and mount the Front panel PCB behind the plate, and connect it to the panel connectors.

*Add photo here*

---

## Wire the ADC analog inputs

## Installing the LED controler and ADC

### TODO 
- The **LED controller PCB** is the VCCS (voltage-controlled current source) and MOSFET board that drives the actinic and detections LEDs from an analog or digital output (ADC or esp32) : see [VCCS Design](../technical-notes/VCCS-design.md) for the full circuit (IRF540N MOSFET, AD797 op-amp, 30 Ω sense resistor, voltage divider on the input).
- The **ADC** is the MCC USB-1808X DAQ board, which generates the actinic/detection waveforms and digitises the preamp outputs — see [Waveform Generation](../technical-notes/waveform-generation.md) for how its three output channels (2 analog + 1 digital trigger) are used.

1. Populate the LED controler PCB with the right components.
2. .....
3. Mount the MCC USB-1808X in the instrument case (or externally, per its enclosure) and connect its USB link to the host PC.
4. Leave the ADC's analog inputs, AO1 (detection flash), and digital trigger port unconnected for now — these are wired up in [Connecting the cables](#connecting-the-cables).
1. Mount the LED controller PCB inside the instrument case in the right position according to the front panel.

*Add photo here*

---

## Installing the esp32

The ESP32 is a secondary controller used for one-shot commands and standalone sequencing (including laser triggering, which the ADC path cannot do — see [Waveform Generation §2](../technical-notes/waveform-generation.md#2-esp32-many-digital-pins-two-8-bit-dacs)). Pin assignments are documented in [Firmware](../../firmware/firmware.md).

1. Seat the ESP32 dev board onto its support board.
2. Mount the assembly inside the instrument case accordint to the front panel holes
3. TODO: wire the cables.
3. Connect the ESP32's USB port to the host PC (or to an internal hub if the instrument exposes a single external USB port).

*Add photo here*

---

## Building Molex connectors

Power distribution inside the instrument case uses Molex KK 396 8-way connectors (male header + female housing) with crimp terminals.

1. Strip a few millimetres of insulation from each wire.
2. Insert the wire into a crimp terminal and crimp it with the crimping tool, checking for a firm mechanical and electrical connection (a light tug test).
3. Insert each crimped terminal into its position in the Molex female housing until it clicks into place, following a consistent pin-out across every harness you build.
4. Solder or mount the matching male header onto the receiving PCB or terminal block.

*Add photo here*

---

## Connecting the cables

### TODO: correct the things 

With all cables installed, make the final connections:

| From | To | Notes |
|---|---|---|
| Preamp PCB output (×2) | ADC analog input (BNC) | Measurement and reference channels |
| ADC AO0 | LED controller (VCCS) input | Actinic level, see [Waveform generation §1.4](../technical-notes/waveform-generation.md#14-channel-0--actinic-light) |
| LED controller output | Actinic LED PCB | See [VCCS design](../technical-notes/VCCS-design.md) |
| ADC AO1 | Detection LED driver | Detection flash amplitude, see [Waveform generation §1.5](../technical-notes/waveform-generation.md#15-channel-1--detection-flash) |
| ADC digital port | Acquisition trigger | See [Waveform generation §1.6](../technical-notes/waveform-generation.md#16-channel-2--the-trigger) |
| ESP32 `actinicDacPin` (GPIO26) | Actinic driver (standalone/manual mode) | See [Firmware](../../firmware/firmware.md#hardware-pins) |
| ESP32 `detectorDacPin` (GPIO25) | Detection LED driver (standalone/manual mode) | Digital on/off only |
| ESP32 `TriggPin` (GPIO12) | External DAQ trigger (optional) | |
| ESP32 `laserChannel_open` / `laserChannel_start` (GPIO18/19) | External laser controller (optional) | Only available on the ESP32 path |
| Power supplies | Molex power harness | Distribute ±15 V, 48 V, and ground to the preamp PCBs, LED controller, and front panel |

1. Connect the Molex power harness first, and check rail voltages at each board's power input **before** connecting any signal cable.
2. Connect the BNC signal cables from each preamp to the ADC.
3. Connect the actinic and detection drive cables from the ADC/LED controller to the LED PCBs.
4. Connect the ESP32 control lines.
5. Power on the instrument and confirm, with the host software, that both detection channels read a stable baseline and that the actinic and detection LEDs respond to test commands before running any real sequence.

*Add photo here*

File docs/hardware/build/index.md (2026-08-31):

# Build

Start here to build your own OpenJTS: the full step-by-step assembly manual and the bill of materials.

```{toctree}
:maxdepth: 2
:caption: Build

full-build-manual
bom
```

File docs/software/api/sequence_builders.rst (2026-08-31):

sequence\_builders
==================

.. automodule:: sequence_builders

.. rubric:: Modules

.. autosummary::
   :toctree:
   :recursive:

   calibration_waveform_builder
   frequency_waveform_builder
   sequence_checker
   sequence_decoder
   sequence_waveform_builder

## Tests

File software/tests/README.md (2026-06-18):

# Testing strategy

Tests live under `software/tests/` and run via `pixi run test` (equivalent to
`pytest software/tests`). Imports resolve the same way they do for the real
app (`pixi run python software/src/main.py`): `software/src` is on
`sys.path` via the `pythonpath` setting in the root `pyproject.toml`, so
modules are imported as `config.config`, `core.event_bus`, etc. — no `src.`
prefix.

## The three tiers

**`unit/`** — fully isolated, no hardware, no GUI, no real I/O. These cover
the modules in `software/src` that are pure logic: `sequence_builders/decoder.py`,
`sequence_builders/control.py`, `utils/data_processing.py`,
`core/workspace_manager.py`, and the parsing/preview path of
`sequence_builders/sequence_waveform_builder.py` (`SequencePreviewBuilder` and
the parsing helpers it shares with `SequenceWaveformBuilder`). Run with:

```
pytest -m unit
```

**`integration/`** — real components wired together through their actual
interfaces (constructors, command queues, public methods), with only the
hardware boundary faked:
- `test_esp32_port_discovery.py` fakes `serial.tools.list_ports.comports()`
  to test `Esp32Base`'s port-matching and its graceful no-hardware fallback.
- `test_worker_hardware_boundary.py` drives `AcquisitionBaseWorker`'s full
  command-queue lifecycle (`configure` → `start` → acquisition steps →
  `stop`/finish) against a hand-written `FakeADC` double (see `conftest.py`)
  instead of a real `mcculw`-backed ADC.

Run with:

```
pytest -m integration
```

`test_worker_hardware_boundary.py` is the template to copy when adding
similar coverage for `SequenceAcquisitionWorker` / `FrequencyAcquisitionWorker`,
or for the calibration/frequency waveform builders and `adc_base`'s voltage
conversion helpers — none of those are covered yet.

**`system/`** — full app smoke tests (real DearPyGUI viewport, real DAQ/ESP32
hardware). Not implemented or run automatically: DearPyGUI needs a live
viewport and the DAQ board/ESP32 need to be physically connected, neither of
which a GitHub-hosted runner can provide. For now this tier stays a manual
bench checklist before releases. Revisit if a self-hosted Windows runner with
an active display session becomes available.

## Markers

`unit`, `integration`, and `system` are registered in `pyproject.toml` so
`pytest -m <marker>` works without warnings. CI runs `pixi run test`, which
covers `unit` and `integration` (there are no `system` tests to collect yet).

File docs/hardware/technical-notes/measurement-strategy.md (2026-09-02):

# Measurement Strategy

As stated before, the JTS works by sending short flashes of non-actinic light. A photodiode captures the light and turns it into a readable voltage via an ADC. You can observe physiological changes of a sample by measuring changes in the light intensity being received.

---

## 1. Sample Timing

It is crucial that the ADC reads a voltage **precisely during the flash of light**. This is easily done by using an external trigger function from the ADC itself or the ESP32.

The sampling point must be chosen carefully:
- **Not too early** in the flash, so as to not waste any of the light being integrated.
- **Not too late**, or digital lag will cause the point to be read after the flash has ended.

In practice, this means a slight delay of about **2-3 µs** before the end of the flash.

---

## 2. DC Component Subtraction

It is important to subtract any DC component that can be present during the measurement. For this, we measure a point just before the flash and subtract it from the point during the flash:

$$I = I_{during} - I_{before}$$

This assumes the baseline is stable over the flash window (a few µs), so any drift in ambient light or LED bias current within that window is not captured by this correction.

---

## 3. Spectrometry Mode

As stated in *Optical Transmission*, when using an "unstable" source of light it was necessary to use two channels to balance out any correlated noise, using the formula:

$$signal = \frac{I_{measurement} - I_{reference}}{I_{reference}}$$

Today, the LEDs used are very stable, and it is possible to use two independent LEDs controlled by the same source. In that case, the two channels no longer share a common noise source, so the formula above no longer cancels shot-to-shot noise the way it did with a single unstable source: the reference channel's noise is uncorrelated with the measurement channel's and simply adds to it instead of subtracting out.

What the reference channel still buys us in this configuration is **drift correction**: it tracks slow, shared-cause changes such as LED aging or temperature-driven intensity shifts over the course of a measurement session, even though it can no longer reject fast, uncorrelated noise. The formula remains useful for that purpose, and since LED stability is now high, the residual noise it introduces is small relative to the signal.

---

## 4. Fluorescence Mode

In fluorescence mode, only **one channel** is needed because the signal is much larger.

---

## 5. Digital Noise Averaging

Finally, to cancel out any digital noise from the ADC, we can use all **8 channels** of the ADC and average them:
- **4** measurement channels
- **4** reference channels

Since ADC noise is uncorrelated across channels, averaging $N$ channels improves the SNR by a factor of $\sqrt{N}$. With $N = 4$, this gives roughly a **2×** reduction in noise for both the measurement and reference signals.

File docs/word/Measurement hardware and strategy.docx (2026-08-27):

Measurement Hardware and strategy

Once the output of the photodiode has been correctly amplified by the preamp circuit, the signal needs to be read by an Analog to Digital Converter :

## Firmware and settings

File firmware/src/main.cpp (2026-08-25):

#include <Arduino.h>
#include "config.h"
#include "system_context.h"
#include "serial_comm.h"
#include "states.h"

// ---------- Contexte global ----------
SystemContext ctx;

void setup()
{
    Serial.begin(115200);

    pinMode(TriggPin, OUTPUT);
    pinMode(laserChannel_start, OUTPUT);
    pinMode(laserChannel_open, OUTPUT);
    pinMode(detectorDacPin, OUTPUT);

    // Max out pad drive strength on the pulse pins so their edges stay sharp
    // even when rail voltage sags under the actinic LED's current draw.
    gpio_set_drive_capability((gpio_num_t)TriggPin, GPIO_DRIVE_CAP_3);
    gpio_set_drive_capability((gpio_num_t)laserChannel_start, GPIO_DRIVE_CAP_3);
    gpio_set_drive_capability((gpio_num_t)laserChannel_open, GPIO_DRIVE_CAP_3);
    gpio_set_drive_capability((gpio_num_t)detectorDacPin, GPIO_DRIVE_CAP_3);

    // Force the actinic pin to a true 0V immediately on every boot/reset
    // (including the reset triggered by the host opening/closing the serial
    // port), instead of leaving it floating until the first command arrives.
    writeActinicLevel(0);
}

void loop()
{
    readSerial(ctx.serial);

    switch (ctx.state)
    {
    case SystemState::IDLE:
        handleIdle(ctx);
        break;

    case SystemState::CONTINUES_FLASH:
        handleContinuesFlash(ctx);
        break;

    case SystemState::CONSTANT_LIGHT:
        handleConstantLight(ctx);
        break;

    case SystemState::SEQUENCE_ACQUISITION:
        handleSequence(ctx);
        break;
    }
}

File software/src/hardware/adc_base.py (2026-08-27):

"""Base ADC driver for MCC DAQ boards.

Provides shared infrastructure used by all concrete ADC subclasses:
buffer allocation/deallocation, a background reader thread that delivers
completed trigger blocks via a queue, AI (analog input) scan configuration, unit-conversion
helpers, and LED output control.
"""

import ctypes
import threading
import time
import queue
import numpy as np

from loguru import logger
from mcculw import ul
from mcculw.enums import (
    ULRange,
    FunctionType,
    ScanOptions,
    InfoType,
    BoardInfo,
    ChannelType,
)

from mcculw.device_info import DaqDeviceInfo

from config.config import config


class ADCError(RuntimeError):
    """Raised when an MCC DAQ operation fails."""


class ADCBase:
    """Base ADC helper for MCC DAQ boards.

    Manages the board connection, buffer lifecycle, a background reader
    thread, AI scan setup, and analog output for LED control.  Subclasses
    must implement :meth:`stop_acquisition` for their specific scan type.

    Attributes:
        board_num (int): MCC board number from ``config.json``.
        dev_info (DaqDeviceInfo | None): Board capability info; ``None`` if
            the board is not detected at startup.
        samples_per_trigger (int): ADC samples captured per external trigger.
        channel_count (int): Number of AI channels scanned per trigger.
        nbr_of_triggers_per_sample (int): Triggers accumulated into one data block.
        adc_bit_depth (int): Full-scale raw count (e.g. 65535 for 16-bit).
        rate (float): Analog output sample rate in Hz, set by subclasses from
            ``config["ADC"]["output_rate"]``; used to pace ``daq_out_scan``.
        actinic_light_max (int): Maximum actinic LED intensity value (config units).
        actinic_light_offset (int): DAC offset for the actinic LED channel.
        detection_light_max (int): Maximum detection LED intensity value (config units).
        detection_light_offset (int): DAC offset for the detection LED channel.
    """

    def __init__(self):
        """Load hardware parameters from config and initialise all internal state."""
        self.board_num = config["ADC"].get("board_num")

        # Initialise dev_info eagerly so subclasses can query capabilities
        # without having to call is_connected() first.
        try:
            self.dev_info = DaqDeviceInfo(self.board_num)
        except Exception:
            self.dev_info = None

        self.samples_per_trigger = config["Sampling"]["samples_per_trigger"]
        self.channel_count = config["ADC"]["channel_count"]
        self.nbr_of_triggers_per_sample = config["Sampling"][
            "nbr_of_triggers_per_sample"
        ]
        self.adc_bit_depth = config["ADC"]["adc_bit_depth"]
        self.actinic_light_max = config["LED"]["actinic_light_max"]
        self.actinic_light_offset = config["LED"]["actinic_light_offset"]
        self.detection_light_max = config["LED"]["detection_light_max"]
        self.detection_light_offset = config["LED"]["detection_light_offset"]

        # Analog output sample rate; overridden by subclasses from config["ADC"]["output_rate"]
        self.rate: float = config["ADC"]["output_rate"]

        # DMA buffer handles and ctypes array pointers
        self._memhandle_acq: int | None = None  # 32-bit acquisition buffer
        self._memhandle: int | None = None  # 16-bit waveform output buffer
        self._acq_buffer_size: int | None = None  # number of values in acq buffer
        self._c_data_array = None  # ctypes view of _memhandle_acq
        self._c_waveform_array = None  # ctypes view of _memhandle

        # Reader thread primitives
        self._reader_thread: threading.Thread | None = None
        self._stop_event = threading.Event()
        self._lock = threading.Lock()
        self._data_queue: queue.Queue = queue.Queue()

    # ------------------------------------------------------------------
    # Device utilities
    # ------------------------------------------------------------------

    def is_connected(self) -> bool:
        """Return ``True`` if at least one MCC DAQ device is detected.

        Also refreshes :attr:`dev_info` as a side effect.
        """
        try:
            devices = ul.get_daq_device_inventory(7, number_of_devices=1)
            self.dev_info = DaqDeviceInfo(self.board_num)
            return bool(devices)
        except Exception as e:
            logger.exception("Error checking device inventory: %s", e)
            return False

    # ------------------------------------------------------------------
    # Buffer management
    # ------------------------------------------------------------------

    def _alloc_acq_buffer_32(self, num_values: int) -> None:
        """Allocate a 32-bit  acquisition buffer of *num_values* samples.

        Any previously allocated acquisition buffer is freed first.

        Args:
            num_values: Total number of 32-bit samples the buffer must hold.

        Raises:
            ADCError: If the MCC library fails to allocate the buffer.
        """
        self._free_acq_buffer()
        self._memhandle_acq = ul.win_buf_alloc_32(num_values)
        if not self._memhandle_acq:
            raise ADCError("Failed to allocate acquisition buffer")
        self._acq_buffer_size = num_values
        self._c_data_array = ctypes.cast(
            self._memhandle_acq, ctypes.POINTER(ctypes.c_ulong)
        )
        logger.debug("Allocated acq buffer (32-bit) size=%d", num_values)

    def _alloc_waveform_buffer_16(self, num_values: int) -> None:
        """Allocate a 16-bit  waveform output buffer of *num_values* samples.

        Any previously allocated waveform buffer is freed first.

        Args:
            num_values: Total number of 16-bit samples the buffer must hold.

        Raises:
            ADCError: If the MCC library fails to allocate the buffer.
        """
        self._free_waveform_buffer()
        self._memhandle = ul.win_buf_alloc(num_values)
        if not self._memhandle:
            raise ADCError("Failed to allocate waveform buffer")
        self._c_waveform_array = ctypes.cast(
            self._memhandle, ctypes.POINTER(ctypes.c_ushort)
        )
        logger.debug("Allocated waveform buffer (16-bit) size=%d", num_values)

    def _free_acq_buffer(self) -> None:
        """Release the 32-bit acquisition  buffer if allocated."""
        if self._memhandle_acq is not None:
            try:
                ul.win_buf_free(self._memhandle_acq)
            except Exception:
                logger.exception("Failed freeing acquisition buffer")
            finally:
                self._memhandle_acq = None
                self._c_data_array = None
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

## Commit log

2026-06-19 initial commt for kicad
    [ESP32_controler.kicad_pcb, ESP32_controler.kicad_sch]
2026-06-22 added kicad schematics
    [ESP32_controler.kicad_pcb, JTS - Controleur V4.kicad_pcb, JTS - Controleur V4.kicad_sch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]
2026-06-22 added multiple sequence add button and corrected frequency config display
2026-06-22 edited Kicad schematics
    [ESP32_controler.kicad_pcb, JTS - Controleur V4.kicad_pcb, JTS - Controleur V4.kicad_sch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]
2026-06-25 added log window
    [JTS - Controleur V4.kicad_pcb, JTS - Controleur V4.kicad_sch]
2026-08-19 you can control with ESP32 but not working perfectly yet
    [adc_calibration.py, adc_calibration_external.py, adc_sequence_external.py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]
2026-08-25 new kicad files
    [JTS - Controleur V4.kicad_pcb, JTS - Controleur V4.kicad_sch, bom.csv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]
2026-08-25 working esp32
2026-08-28 testing new docs structure
    [bom.ods]
2026-08-31 updating ReadTheDocs
    [bom.ods]
2026-11-03 ESP32 ext clock trigger
2026-11-03 frequency in ESP32
